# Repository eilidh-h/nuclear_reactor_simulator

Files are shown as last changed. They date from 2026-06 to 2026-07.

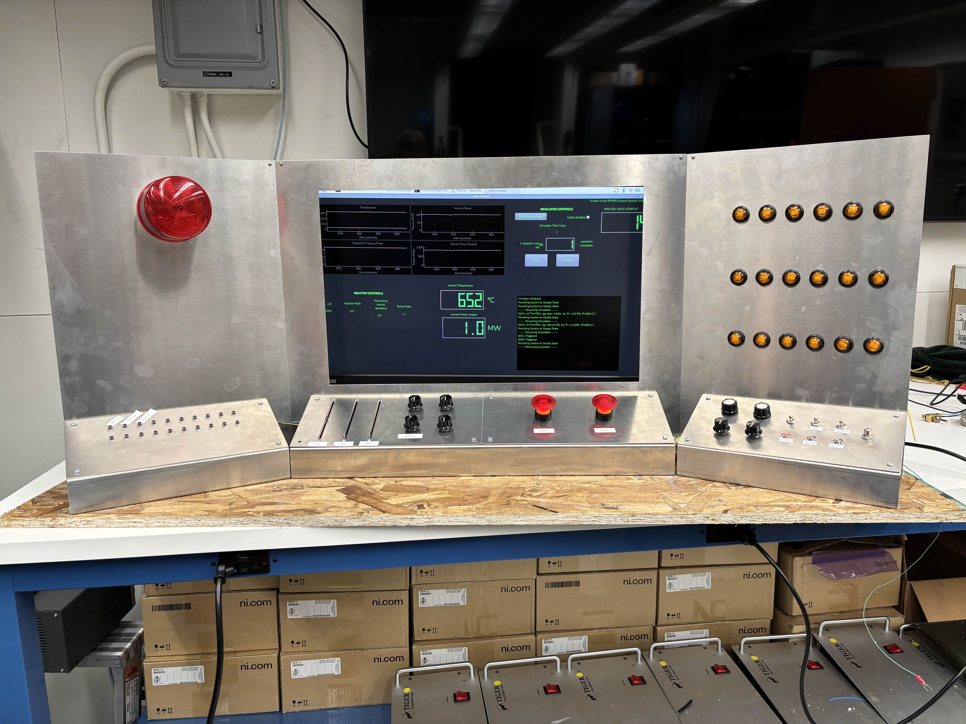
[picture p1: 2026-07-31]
Current Design Files/Case Files/Final Unit.jpg

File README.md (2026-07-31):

# CANDU Nuclear Reactor Simulator

# Project Overview
This project is a hardware-integrated CANDU reactor simulator built using Python, PyQt6, Raspberry Pi GPIO, ADC/DAC hardware, and a real-time reactor simulation backend. The system provides physical controls and indicators for interacting with a simulated reactor plant. This repository also houses a software only version of the simulation which can be run on any computer and does not require hardware inputs.

---

# Repository Structure

```text
main/
├── Current Design Files/        # Contains all hardware information
    ├── Datasheets/                  # Contains datasheets for parts used in the original design
    ├── Case Files/                  # Contains .SLDPRT drawings for the case and parts used
    ├── Circuitry Files/             # Contains modular circuit designs for each type of input
    ├── Fission Vision - Simulator Parts list.xlsx # Master list of all parts and costings
├── Hardware Version/            # Scripts for simulation with hardware
    ├── ADS1256.py                   # ADC driver
    ├── DAC8532.py                   # DAC driver
    ├── Hardware_Integrated_GUI.ui   # Qt Designer UI file
    ├── candu_realtime_sim.py        # Reactor simulation backend
    ├── main.py                      # hardware main script
    ├── pinouts.py                   # Raspberry Pi Pin out config
├── Software-Only Version/       # Scripts for simulation with software only
    ├── Software_Only_GUI.ui         # Qt Designer UI file
    ├── candu_realtime_sim.py        # Reactor simulation backend
    ├── main.py                      # software-only main script
└── README.md
```

---

# Hardware Requirements
The full parts list can be found in ```main/Current Design Files/Fission Vision - Simulator Parts List.xlsx ```

## Core Hardware

* Raspberry Pi 4 or 5
* MicroSD Card
* Power Supply
* Display/Monitor
* Keyboard/Mouse

## I/O Hardware

* ADS1256 ADC Module
* DAC8532 DAC Module
* Potentiometers / Rotary Knobs
* Toggle Switches
* Push Buttons
* LEDs / Indicator Lights
* Siren / Buzzer
* Wiring / Breadboard / PCB

---

# Software Requirements
## Operating System

* Raspberry Pi OS: Raspberry Pi OS (64-bit)

## Python Version

* Python 3.X Recommended

## Required Python Libraries

```bash
pip install pyqt6
pip install pyqtgraph
pip install numpy
pip install RPi.GPIO
pip install threading
```
---
# Software controls Overview

### `speed`
Sets the reactor simulation speed relative to real time.

- **Units:** Reactor seconds per wall-clock second
- **Example:**
  ```text
  speed = 60
  ```
  This means **1 real second = 1 reactor minute**.

---

### `goal`
Sets the operator's target power fraction.

This value is intended primarily for the simulator's game mode, where the operator attempts to match the requested power level.

---

### `lzc`
Sets the average Liquid Zone Controller (LZC) fill level.

- **Units:** Percent (%)
- **Neutral value:** `50%`
- **Behavior:**
  - Lower fill → Positive reactivity → Reactor power tends to increase.
  - Higher fill → Negative reactivity → Reactor power tends to decrease.

---

### `adj`
Sets the adjuster rod withdrawal fraction.

- **Range:** `0–1`
- **Behavior:**
  - Higher values correspond to greater adjuster rod withdrawal.
  - Increased withdrawal adds **positive reactivity**.

---

### `mca`
Sets the Mechanical Control Absorber (MCA) insertion fraction.

- **Range:** `0–1`
- **Behavior:**
  - Higher insertion results in **more negative reactivity**.

---

### `refuel`
Sets the continuous online refuelling command.

- **Range:** `0–2`
- Implemented as a continuous control rather than discrete fuelling events.
- Designed to map naturally to GUI sliders or analogue hardware controls.

---

### `safety`
Enables or disables the automatic reactor protection system.

When enabled, automatic **stepback** and **shutdown** logic will operate if required.

---

### `trip sds1`
Manually initiates a shutdown using **Shutdown System 1 (SDS1)**.

---

### `trip sds2`
Manually initiates a shutdown using **Shutdown System 2 (SDS2)**.

---

### `reset sds`
Clears the shutdown latches.

This command is only accepted when reactor power is **below 1% full power**.

---

### `reset steady`
Resets the simulator to the nominal startup state.

This performs a complete re initialization of the reactor state.

# Known simulation simplifications
* one delayed-neutron group instead of six
* lumped thermal states instead of detailed HTS / SG thermodynamics
* normalized poison states instead of full iodine/xenon number densities
* simplified shutdown logic compared with plant-grade 2-out-of-3 voting

---

# Future Improvements

Ideas for possible enhancements:
* Developing lesson materials for use with the simulator
* Creating interesting scenarios (power grid failure, start the reactor from cold, etc.)
* Adding an automatic mode like real CANDU reactors with a PID controller based on the steam pressure error
* Adding a graphic of a CANDU plant to the GUI to show how energy moves around the plant
* More robust simulation feedback and event logs
* Implementing a “power-matching” game mode
* Additional speed and performance testing and improvement
* Further refinements of the case to improve transport, packing, and ease of use

---

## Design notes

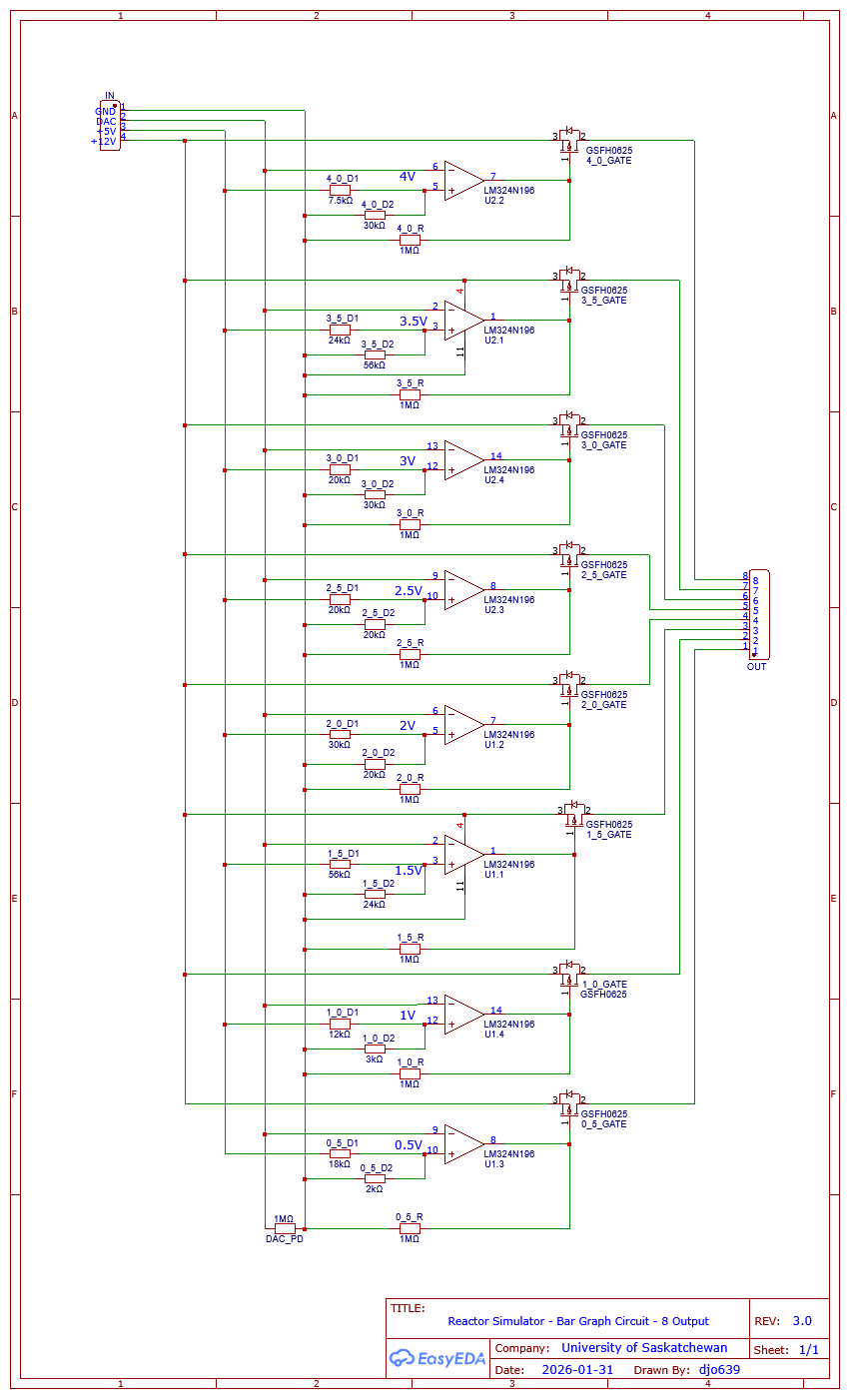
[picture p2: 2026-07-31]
Current Design Files/Circuitry Files/Schematics/Bar Graph - Schematic.png

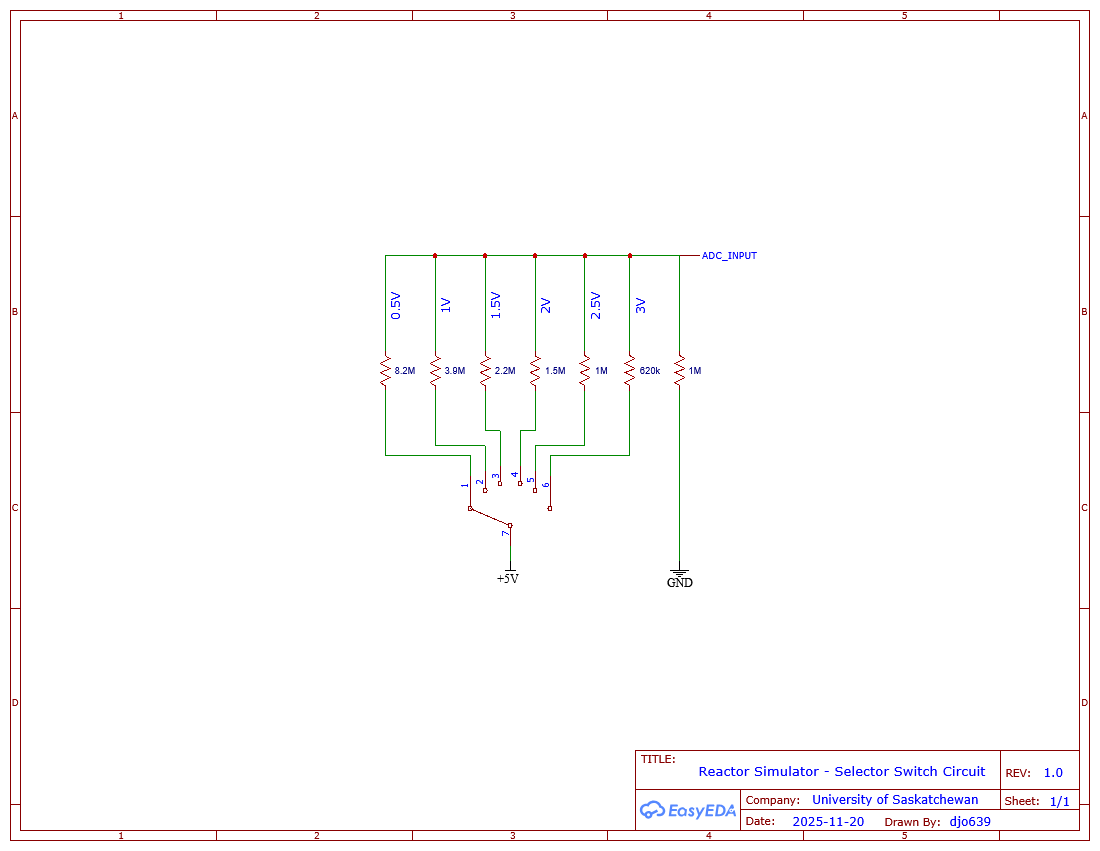
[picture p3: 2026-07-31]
Current Design Files/Circuitry Files/Schematics/Selector Swtich - Schematic.png

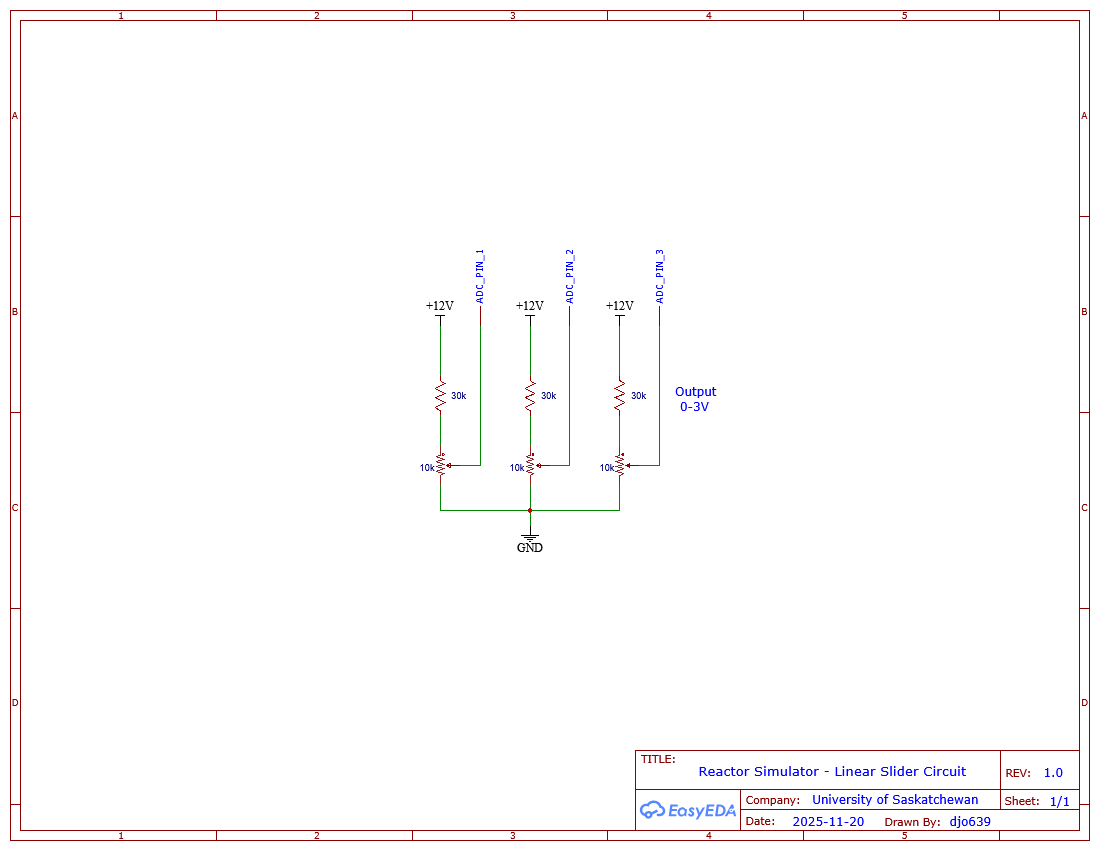
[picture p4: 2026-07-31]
Current Design Files/Circuitry Files/Schematics/3 Slider Circuit - Schematic.png

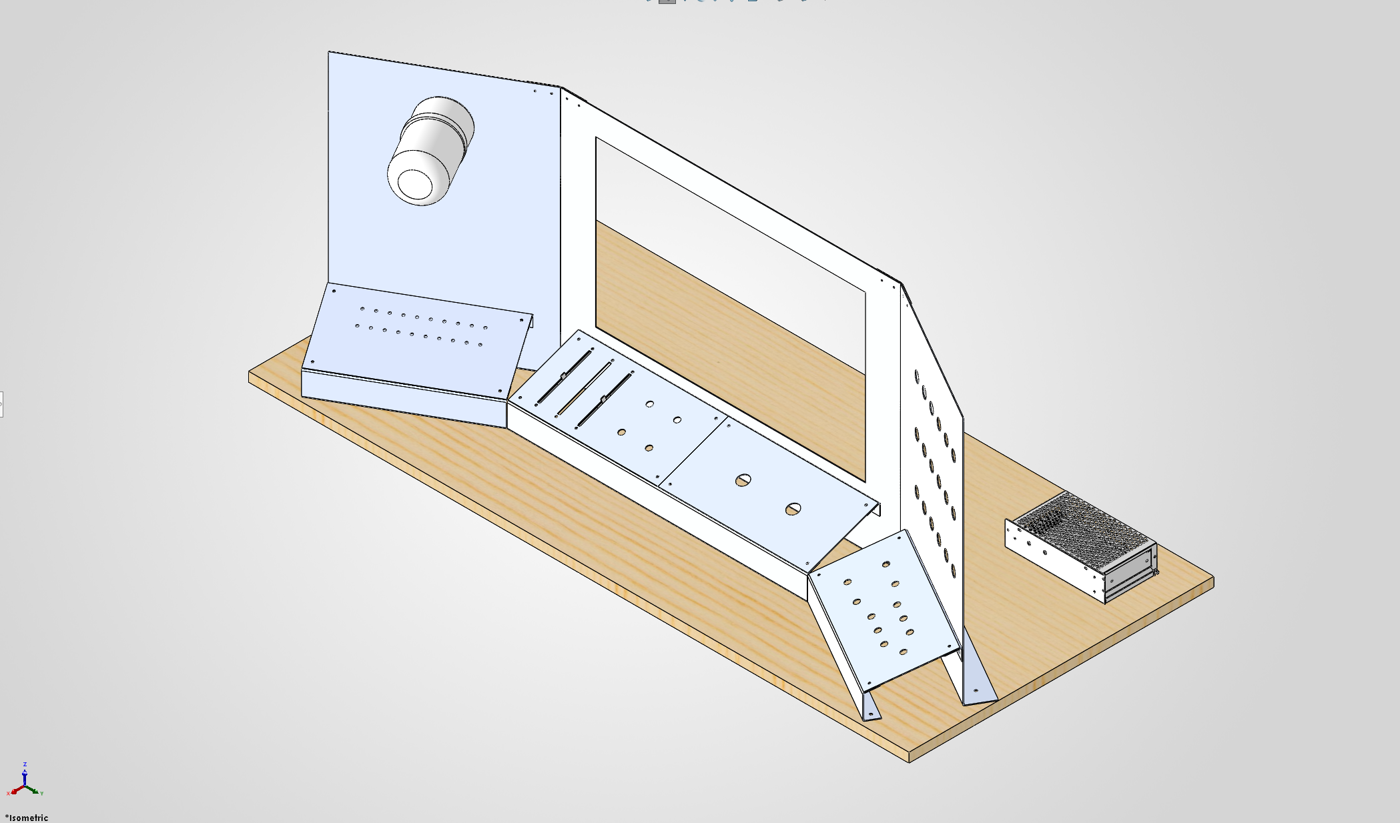
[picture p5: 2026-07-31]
Current Design Files/Case Files/Simulator Case - Solidworks Render.png

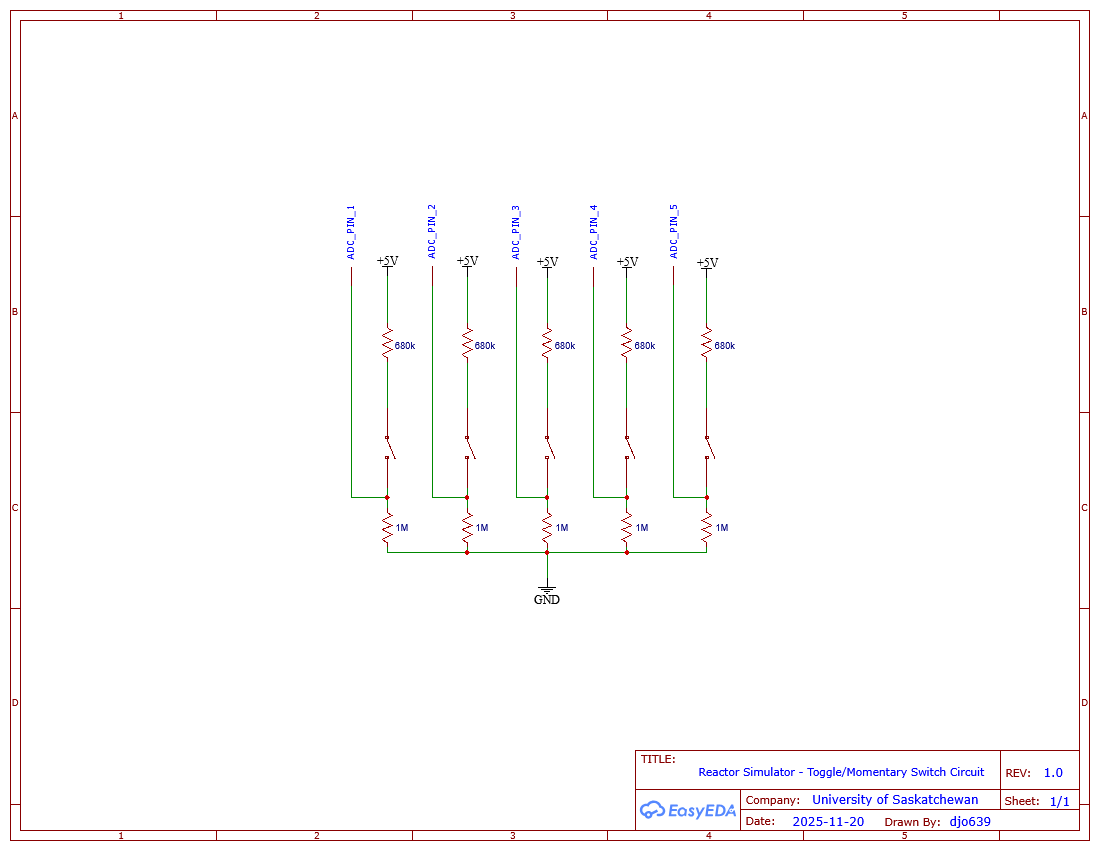
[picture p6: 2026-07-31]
Current Design Files/Circuitry Files/Schematics/Momentary_Toggle Switch - Schematic.png

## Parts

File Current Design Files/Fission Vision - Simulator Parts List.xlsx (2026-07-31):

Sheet: Complete Assembly List
COMPLETE ASSEMBLY LIST
*NOTE: Assembly details and component lists can be found within the sub-sheet of the same name. Costs are estimates only and do not include labor.
Type | Subtype | Component/Assembly | Name | Use | QTY | Approx Cost | Notes
Case | Back Panel | Assembly | Heat/Power/Pressure Panel | Vertical aluminum panel to support bar graph lights | 1 | $29.50
Case | Back Panel | Assembly | Monitor Panel | Vertical aluminum panel to support GUI monitor | 1 | $32.00
Case | Back Panel | Assembly | Siren Panel | Vertical aluminum panel to support meltdown siren | 1 | $41.00
Case | Control Panel | Assembly | Indicator | Aluminum panel to contain hazard/warning indicator lights | 1 | $41.00
Case | Control Panel | Assembly | Reactor Control | Aluminum panel to contain reactor controls for parameters such as Liquid Zone Control level, Adjuster Rods position, etc | 1 | $54.35
Case | Control Panel | Assembly | SCRAM | Alumimun panel to contain Reactor SCRAM controls | 1 | $35.05
Case | Control Panel | Assembly | Simulation Control | Aluminum panel to contain simulation controls for parameters such as pause, play, simulation speed, etc | 1 | $57.80
Case | Structure | Assembly | Simulator Base | Provides mounting points for simulator case, circuitry, and other components | 1 | $39.00 | 5/16" thickness minimum - other dimensions and hole pattern as per SolidWorks file
Case | Structure | Assembly | Mounting Hardware | Plates and components required to interconnect case panels | 1 | $48.70
Electrical | Circuit | Assembly | Bar Graph | Takes DAC output and converts to scaling bar graph lights | 2 | $40.60
Electrical | Circuit | Assembly | Pull Down | Pulls toggle/momentary/logic pins to 0V to prevent floating input errors | 1 | $11.25
Electrical | Circuit | Assembly | Selector Switch | Converts multi-output selector switch to single pin GPIO input | 1 | $11.10
Electrical | Circuit | Assembly | Siren Trigger | Allows Raspberry Pi to trigger 12V siren with low power 3.3V | 1 | $8.70
Electrical | Terminal | Component | Conn Barrier Strip | Local Voltage/Ground Mustering Point | 4 | $10.00 | 10 position - 0.374" - 1 for each third of the simulator triptych and 1 at rear for Pi and accessories
Electrical | Terminal | Component | D-SUB Connector (Female) | Provides quick connect/disconnect signal and power passthrough between Pi and controls | 1 | $2.50 | 50-Pin
Electrical | Terminal | Component | D-SUB Connector (Male) | Provides quick connect/disconnect signal and power passthrough between Pi and controls | 1 | $2.50 | 50-Pin
Electrical | Power | Component | Power Cable | Provides 120VAC wall power to power supply | 1 | $5.00 | 3-Pin 120VAC plug to bare wire or fork terminal - Connect directly to power supply or through rated toggle switch
Electrical | Power | Component | Power Supply | Powers all simulator functions except montior | 1 | $75.00 | 120VAC to Dual Output 5VDC/12VDC
Electrical | Power | Assembly | Wiring Harness | Connects all panels to central D-SUB Passthrough | 1 | $39.25
Electrical | Computation | Component | Raspberry Pi 5 | Hosts Simulation. Processes Analog IO | 1 | $250.00
Electrical | Raspberry Pi Module | Component | ADC/DAC | Allows Pi to Process Continuous IO | 1 | $60.00
Electrical | Raspberry Pi Module | Component | Micro HDMI to HDMI + Power | Allows Pi to accept standard HDMI interface. Enables Pi to run off 5V Power Supply | 1 | $20.00
Peripheral | GUI | Component | Monitor | Displays GUI | 1 | $150.00 | 27" minimum for proper fitment in panel cutout
Peripheral | GUI | Component | Monitor Arm | Holds monitor in place while still allowing for repositioning | 1 | $50.00
Peripheral | GUI | Component | Mouse | Initialize Reactor Simulator (Not required while simulation is running) | 1 | $10.00
Approximate Total Simulator Cost |  | $1124.30

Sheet: Indicator Control Panel
Indicator Control Panel - Part List
Name | Use | Voltage | QTY | Approx Per Unit Cost | Approx Cost | Notes
3mm Discrete LED Bulb | Simulator analog indication - warning lights | 3.3 | 20 | $0.50 | $10.00
3mm LED Panel Mount | Mount lights to control panel | - | 20 | $0.50 | $10.00
10-Pin Molex Connector (Male) | Quick Disconnect between panel and simulator | - | 4 | $1.25 | $5.00 | 2 for signal, 2 for ground
16ga Aluminum Sheet | Control Mounting | - | 1 | $10.00 | $10.00 | Dimensioned as per Solidworks file. Assumes Aluminum price of $5 per square foot
Heat Shrink 1/8" | Isolation | - | 1 | $1.00 | $1.00 | 1-2ft, 2:1 shrink ratio sufficient
Heat Shrink 1/4" | Isolation | - | 1 | $1.00 | $1.00 | 1-2ft, 2:1 shrink ratio sufficient
Wire | 20-22AWG | - | 10 | $0.30 | $3.00 | 10ft - Four separate colors prefered (12V, 5V, Signal, Ground)
820 kΩ Resistor | LED Resistance | 3.3 | 20 | $0.05 | $1.00 | Assumes Red LED: Forward Voltage 1.75V and Current 2mA
 |  |  |  | Approximate Total Cost | $41.00

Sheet: Reactor Control Panel
Reactor Control Panel - Part List
Name | Use | Voltage | QTY | Approx Per Unit Cost | Approx Cost | Notes
Rotatry Potentiometer | Analog Simulator Inputs | 12 | 4 | $2.50 | $10.00
Rotatry Potentiometer Cap | Simulator Control Surface | - | 4 | $0.75 | $3.00
Slider Potentiometer | Analog Simulator Inputs | 12 | 3 | $6.00 | $18.00
Slider Potentiometer Cap | Simulator Control Surface | - | 3 | $1.00 | $3.00
3-Pin Molex Connector (Male) | Quick Disconnect between panel and simulator | - | 1 | $1.25 | $1.25 | Slider pots signal out
4-Pin Molex Connector (Male) | Quick Disconnect between panel and simulator | - | 1 | $1.25 | $1.25 | Rotary pots signal out
8-Pin Molex Connector (Male) | Quick Disconnect between panel and simulator | - | 2 | $1.25 | $2.50 | 1 for common 12V supply, 1 for common ground
16ga Aluminum Sheet | Control Mounting | - | 1 | $10.00 | $10.00 | Dimensioned as per Solidworks file. Assumes Aluminum price of $5 per square foot
Heat Shrink 1/8" | Isolation | - | 1 | $1.00 | $1.00 | 1-2ft, 2:1 shrink ratio sufficient
Heat Shrink 1/4" | Isolation | - | 1 | $1.00 | $1.00 | 1-2ft, 2:1 shrink ratio sufficient
Wire | 20-22AWG | - | 10 | $0.30 | $3.00 | 10ft - Four separate colors prefered (12V, 5V, Signal, Ground)
30 kΩ Resistance | Convert 12V Slider Input to output 0-3V | 12 | 3 | $0.05 | $0.15
750 kΩ Resistance | Convert 12V Potentiometer Input to output 0-3V | 12 | 4 | $0.05 | $0.20
 |  |  |  | Approximate Total Cost | $54.35
 |  |  |  |  |  |  | 0.75

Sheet: SCRAM Control Panel
SCRAM Control Panel - Part List
Name | Use | Voltage | QTY | Approx Per Unit Cost | Approx Cost | Notes
Lit Emergency Stop Slap Switch | Simulator analog control | 5 | 2 | $10.00 | $20.00 | Wire so that switch light in series with switch contact
2-Pin Molex Connector (Male) | Quick Disconnect between panel and simulator | - | 3 | $1.25 | $3.75 | 1 for both switch outputs, 1 for common 5V supply, 1 for common ground
16ga Aluminum Sheet | Control Mounting | - | 1 | $10.00 | $10.00 | Dimensioned as per Solidworks file. Assumes Aluminum price of $5 per square foot
Wire | 20-22AWG | - | 4 | $0.30 | $1.20 | 4ft - Four separate colors prefered (12V, 5V, Signal, Ground)
680 kΩ Resistance | Convert 5V switch output 3V | 5 | 2 | $0.05 | $0.10 | Attach resistor to power supply lead of switch - signal lead must be connected to Pi through Pulldown circuit.
 |  |  |  | Approx Total Cost | $35.05

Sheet: Simulation Control Panel
Simulator Control Panel - Part List
Name | Use | Voltage | QTY | Approx Per Unit Cost | Approx Cost | Notes
Rotatry Potentiometer | Analog Simulator Inputs | 12 | 2 | $2.50 | $5.00
Rotatry Potentiometer Cap | Simulator Control Surface | - | 2 | $0.75 | $1.50
Selector Switch | Analog Simulator Inputs | 5 | 2 | $10.00 | $20.00
Selector Switch Cap | Simulator Control Surface | - | 2 | $1.00 | $2.00
Toggle Switch | Analog Simulator Inputs | 5 | 7 | $2.00 | $14.00
10-Pin Molex Connector (Male) | Quick Disconnect between panel and simulator | - | 2 | $1.25 | $2.50
16ga Aluminum Sheet | Control Mounting | - | 1 | $10.00 | $10.00 | Dimensioned as per Solidworks file. Assumes Aluminum price of $5 per square foot
Heat Shrink 1/8" | Isolation | - | 1 | $1.00 | $1.00 | 1-2ft, 2:1 shrink ratio sufficient
Heat Shrink 1/4" | Isolation | - | 1 | $1.00 | $1.00 | 1-2ft, 2:1 shrink ratio sufficient
680 kΩ Resistance | Convert 5V switch output 3V | 5 | 6 | $0.05 | $0.30 | Attach resistor to power supply lead of switch - signal lead must be connected to Pi through Pulldown circuit.
750 kΩ Resistance | Convert 12V Potentiometer Input to output 0-3V | 12 | 4 | $0.05 | $0.20
Wire | 20-22AWG | - | 1 | $0.30 | $0.30 | 20ft - Four separate colors prefered (12V, 5V, Signal, Ground)
 |  |  |  | Approx Total Cost | $57.80

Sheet: Simulator Base
Simulator Base - Part List
Name | Use | QTY | Approx Per Unit Cost | Approx Cost | Notes
Hanger Bolts | Case Mounting Point | 20 | $0.15 | $3.00 | M4 x 25mm
Washer | Mounting Hardware | 20 | $0.05 | $1.00 | M4
Wing Nut | Mounting Hardware | 20 | $0.25 | $5.00 | M4
Plywood | Simulator Base | 1 | $30.00 | $30.00 | 5/16" minimum - complete dimensions and hole pattern available in SolidWorks file
 |  |  | Approx Total Cost | $39.00

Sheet: Monitor Panel
Monitor Panel - Part List
Name | Use | QTY | Approx Per Unit Cost | Approx Cost | Notes
14ga Aluminum Sheet |  | 4 | $8.00 | $32.00 | Dimensioned as per Solidworks file. Assumes Aluminum price of $8 per square foot
 |  |  | Approx Total Cost | $32.00

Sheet: Siren Panel
Siren Panel - Part List
Name | Use | QTY | Approx Per Unit Cost | Approx Cost | Notes
Beacon w/ Siren | Alarm | 1 | $25.00 | $25.00 | Beacon Preferred. Avoid strobe.
14ga Aluminum Sheet | Simulator Base | 2 | $8.00 | $16.00 | Dimensioned as per Solidworks file. Assumes Aluminum price of $8 per square foot
 |  |  | Approx Total Cost | $41.00

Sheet: HPP Panel
Heat/Power/Pressure Panel - Part List
Name | Use | QTY | Approx Per Unit Cost | Approx Cost | Notes
Trailer Side Clearance/Marker LEDs - Amber | Bar Graph Indication | 18 | $0.75 | $13.50 | 3/4" dia - 12VDC
14ga Aluminum Sheet |  | 2 | $8.00 | $16.00 | Dimensioned as per Solidworks file. Assumes Aluminum price of $5 per square foot
 |  |  | Approx Total Cost | $29.50

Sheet: Mounting Hardware
Mounting Hardware - Part List
Name | Use | QTY | Approx Cost Per Unit | Approx Cost | Notes
Angle Bracket | Ties vertical panels together | 2 | $0.10 | $0.20 | 150° bend - 16ga aluminum preferred
Bottom Panel Mount - Center | Mounting Plate | 1 | $5.00 | $5.00 | Dimensions, bend angle, and hole pattern as per Solidworks file
Bottom Panel Mount - Wing | Mounting Plate | 2 | $5.00 | $10.00 | Dimensions, bend angle, and hole pattern as per Solidworks file
Machine Screw - Cheesehead - M3 | Bracket Mounting | 4 | $0.10 | $0.40 | Slotted - 0.25" Long - Cheesehead for aesthetics only. Substitute with whatever you like
Machine Screw - Cheesehead - M4 | Panel Mounting | 16 | $0.10 | $1.60 | Slotted - 0.5" Long - Cheesehead for aesthetics only. Substitute with whatever you like
Machine Screw - Panhead - M5 | Panel Mounting | 10 | $0.10 | $1.00 | Robertson - 0.5" Long
Rivnut | Panel Mounting | 16 | $0.10 | $1.60 | M4 - Steel or Aluminum
Upper Panel Mount - Center | Mounting Plate | 1 | $5.00 | $5.00 | Dimensions, bend angle, and hole pattern as per Solidworks file
Upper Panel Mount - Wing | Mounting Plate | 2 | $5.00 | $10.00 | Dimensions, bend angle, and hole pattern as per Solidworks file
Washer - M3 | Bracket Mounting | 8 | $0.05 | $0.40 | -
Washer - M5 | Panel Mounting | 20 | $0.05 | $1.00 | -
Wingnut - M5 | Panel Mounting | 10 | $0.25 | $2.50 | -
Nylon Stand-Off | Circuit Mounting | 20 | $0.50 | $10.00 | #6UNC - 0.5" Long
 |  |  | Approximate Total Cost | $48.70

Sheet: Bar Graph Circuit
Bar Graph Circuit - Part List
Name | Use | QTY | Approx Price Per Unit | Approx Cost | Notes
1 MΩ Resistance | Pulldown Resistor | 7 | $0.05 | $0.35 | 0.25 W - Axial Through Hole
12 kΩ Resistance | Comparator Reference Divider | 1 | $0.05 | $0.05 | 0.25 W - Axial Through Hole
18 kΩ Resistance | Comparator Reference Divider | 1 | $0.05 | $0.05 | 0.25 W - Axial Through Hole
2 kΩ Resistance | Comparator Reference Divider | 1 | $0.05 | $0.05 | 0.25 W - Axial Through Hole
2 Position Screw Terminal | Wire-to-board connection | 2 | $0.65 | $1.30 | 0.1" pitch - 16-30AWG
20 kΩ Resistance | Comparator Reference Divider | 4 | $0.05 | $0.20 | 0.25 W - Axial Through Hole
24 kΩ Resistance | Comparator Reference Divider | 1 | $0.05 | $0.05 | 0.25 W - Axial Through Hole
3 kΩ Resistance | Comparator Reference Divider | 1 | $0.05 | $0.05 | 0.25 W - Axial Through Hole
30 kΩ Resistance | Comparator Reference Divider | 2 | $0.05 | $0.10 | 0.25 W - Axial Through Hole
56 kΩ Resistance | Comparator Reference Divider | 1 | $0.05 | $0.05 | 0.25 W - Axial Through Hole
6 Position Screw Terminal | Wire-to-board connection | 1 | $2.35 | $2.35 | 0.1" pitch - 16-30AWG
Hook-up Wire | - | 3 | $0.30 | $0.90 | Assuming 3ft of 22AWG solid core - various colors preferred
IC Socket | IC-to-board connection | 2 | $0.20 | $0.40 | DIP-14
LM324 Op-Amp | Comparator Trigger | 2 | $0.35 | $0.70 | Part Number: LM324N (Texas Instruments)
Protoboard | Circuit PCB | 1 | $8.00 | $8.00 | 100mm x 80mm - 0.1" Pitch - Strip type board preferred
P-Type Mosfet | Isolation/Amplification | 6 | $0.95 | $5.70 | Part Number: GSFH0625 (Good-Ark Semiconductor)
 |  |  | Approx Total Cost | $20.30

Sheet: Siren Trigger Circuit
Siren Trigger Circuit - Part List
Name | Use | QTY | Approx Price Per Unit | Approx Cost | Notes
1 MΩ Resistance | Pulldown Resistor | 3 | $0.05 | $0.15 | 0.25 W - Axial Through Hole
2 Position Screw Terminal | Wire-to-board connection | 3 | $0.65 | $1.95 | 0.1" pitch
200 kΩ Resistance | Comparator Reference Divider | 1 | $0.05 | $0.05 | 0.25 W - Axial Through Hole
470 kΩ Resistance | Comparator Reference Divider | 1 | $0.05 | $0.05 | 0.25 W - Axial Through Hole
IC Socket | IC-to-board connection | 1 | $0.20 | $0.20 | DIP-14
LM324 Op-Amp | Comparator Trigger | 1 | $0.35 | $0.35 | Part Number: LM324N (Texas Instruments)
Protoboard | Circuit PCB | 1 | $5.00 | $5.00 | 31mm x 76mm - 0.1" Pitch - Bus type board preferred
P-Type Mosfet | Isolation/Amplification | 1 | $0.95 | $0.95 | Part Number: GSFH0625 (Good-Ark Semiconductor)
 |  |  | Approx Total Cost | $8.70

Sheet: Selector Switch Circuit
Selector Switch Circuit - Part List
*NOTE: Assumes 2 switch circuit with 6 positions each
Name | Use | QTY | Approx Cost Per Unit | Approx Cost | Notes
1 MΩ Resistance | Pulldown Resistor | 2 | $0.05 | $0.10 | 0.25 W - Axial Through Hole
2 Position Screw Terminal | Wire-to-board connection | 2 | $0.65 | $1.30 | 0.1" pitch
6 Position Screw Terminal | Wire-to-board connection | 2 | $2.35 | $4.70 | 0.1" pitch
Protoboard | Circuit PCB | 1 | $5.00 | $5.00 | 31mm x 76mm - 0.1" Pitch - Bus type board preferred
 |  |  | Approx Total Cost | $11.10

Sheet: Pull Down Circuit
Pull Down Circuit - Part List
*NOTE: Assumes 8 position circuit
Name | Use | QTY | Approx Cost per Unit | Approx Cost | Notes
1 MΩ Resistance | Pulldown Resistor | 8 | $0.05 | $0.40 | 0.25 W - Axial Through Hole
2 Position Screw Terminal | Wire-to-board connection | 9 | $0.65 | $5.85 | 0.1" pitch
Protoboard | Circuit PCB | 1 | $5.00 | $5.00 | 31mm x 76mm - 0.1" Pitch - Bus type board preferred
 |  |  | Approximate Total Cost | $11.25

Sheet: Wiring Harness
Wiring Harness - Part List
Name | Use | QTY | Approx Price per Unit | Approx Cost | Notes
Wire | - | 50 | $0.30 | $15.00 | 20-22AWG - 50ft - Four separate colors prefered (12V, 5V, Signal, Ground) - Can substitute for multiconductor cable were appropriate.
Fork Terminal (Red) | Electrical Connections | 25 | $0.10 | $2.50
Butt Splice Connector (Red) | Electrical Connections | 25 | $0.10 | $2.50
Fork Terminal (Blue) | Electrical Connections | 10 | $0.10 | $1.00
Butt Splice Connector (Blue) | Electrical Connections | 20 | $0.10 | $2.00
10-Pin Molex Connector (Female) | Quick Disconnect between panel and simulator | 6 | $1.25 | $7.50
8-Pin Molex Connector (Female) | Quick Disconnect between panel and simulator | 2 | $1.25 | $2.50
4-Pin Molex Connector (Female) | Quick Disconnect between panel and simulator | 1 | $1.25 | $1.25
3-Pin Molex Connector (Female) | Quick Disconnect between panel and simulator | 1 | $1.25 | $1.25
2-Pin Molex Connector (Female) | Quick Disconnect between panel and simulator | 3 | $1.25 | $3.75
40-pin GPIO connector ribbon cable | Quick Disconnect between controls and Raspberry Pi | 1 | $5.00 | $5.00
 |  |  | Approx Total Cost | $39.25

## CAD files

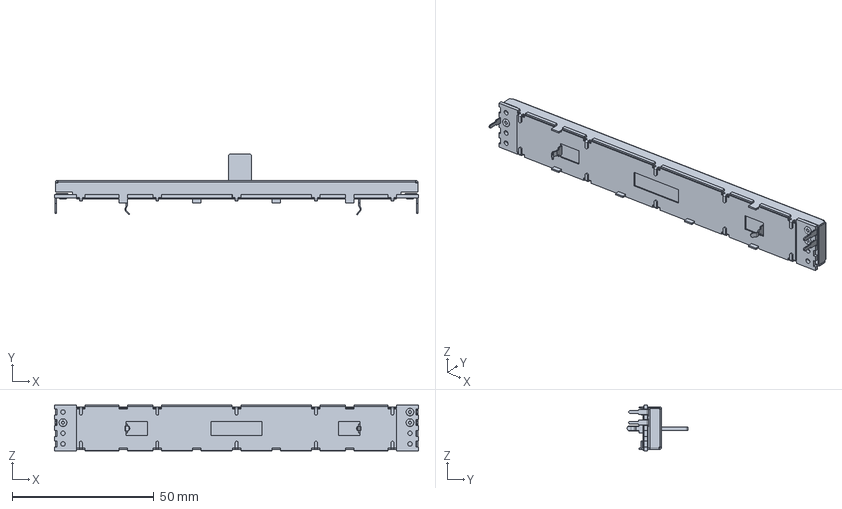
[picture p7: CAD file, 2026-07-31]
Current Design Files/Case Files/Part & Assembly Files/Slider - ptb0143-2010bp.stp
128.5 x 21.4 x 16.2 mm

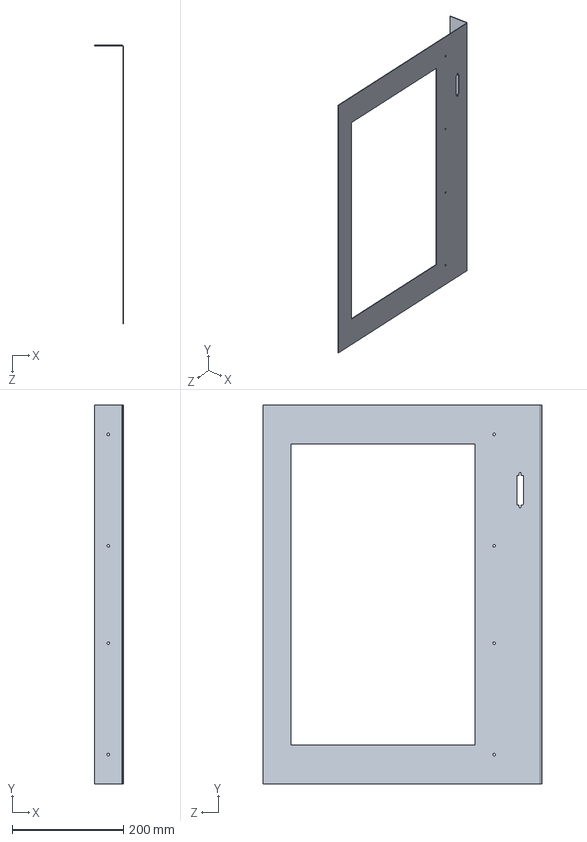
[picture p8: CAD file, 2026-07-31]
Current Design Files/Case Files/Part & Assembly Files/SIM_CNTR_001.SLDPRT
52.5 x 680.0 x 500.0 mm

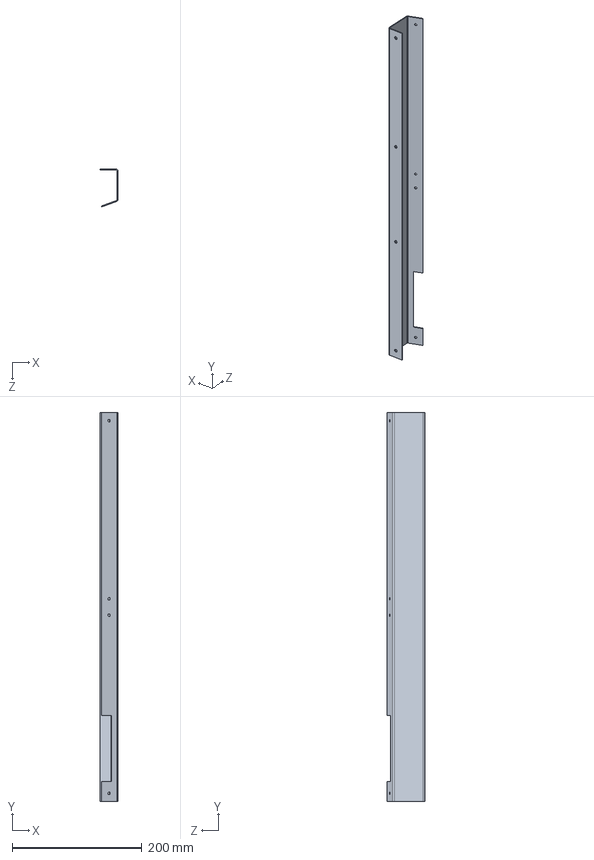
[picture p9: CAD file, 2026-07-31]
Current Design Files/Case Files/Part & Assembly Files/SIM_PMNT_CTR_BTM_001.SLDPRT
27.9 x 600.0 x 58.4 mm

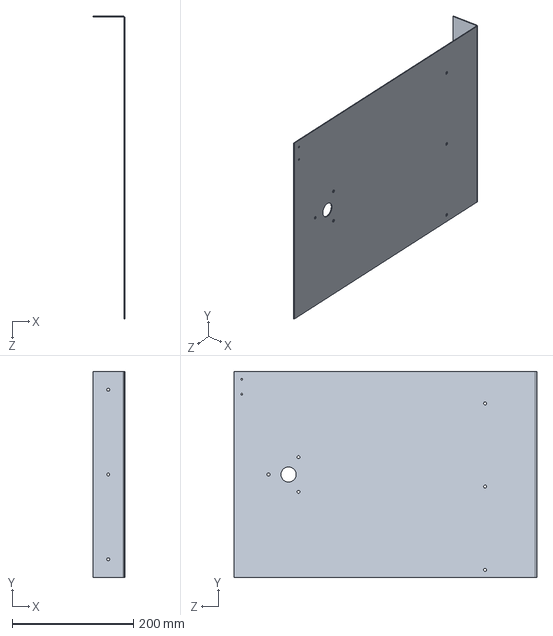
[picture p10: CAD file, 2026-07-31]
Current Design Files/Case Files/Part & Assembly Files/SIM_WING_LEFT_001.SLDPRT
52.5 x 340.0 x 500.0 mm

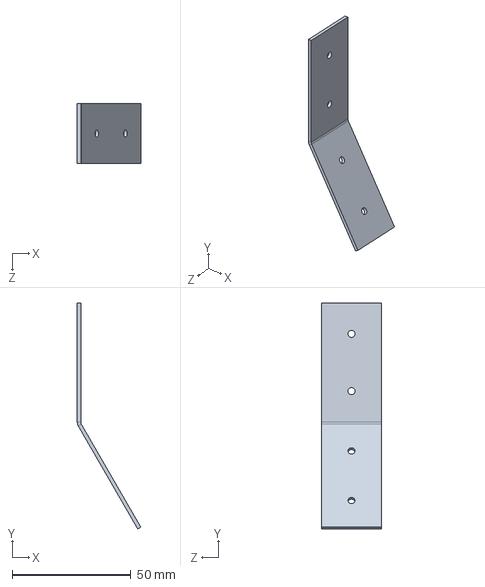
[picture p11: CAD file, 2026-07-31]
Current Design Files/Case Files/Part & Assembly Files/SIM_BRACKET_001.SLDPRT
26.8 x 95.2 x 25.4 mm

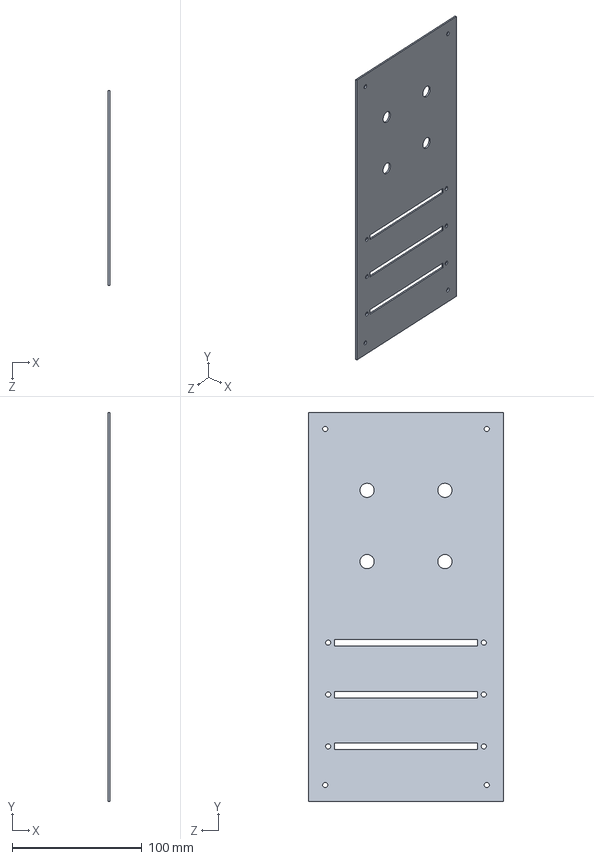
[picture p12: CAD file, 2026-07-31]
Current Design Files/Case Files/Part & Assembly Files/SIM_REACTOR_PNL_001.SLDPRT
1.52 x 300.0 x 150.0 mm

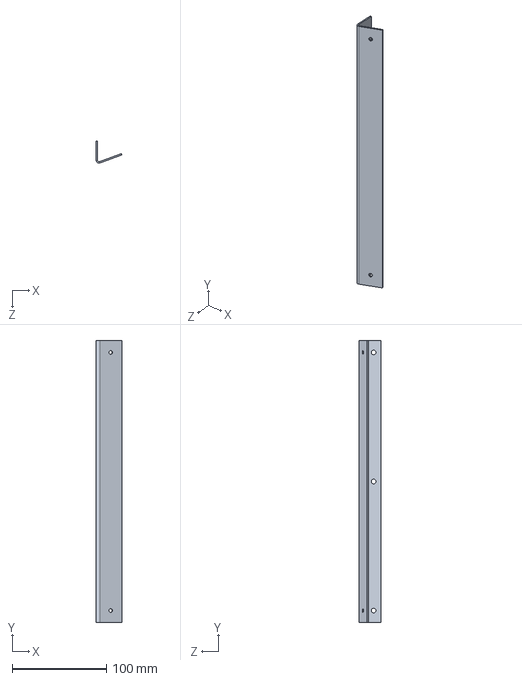
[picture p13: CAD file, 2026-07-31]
Current Design Files/Case Files/Part & Assembly Files/SIM_PMNT_W_TOP_001.SLDPRT
27.5 x 300.0 x 23.7 mm

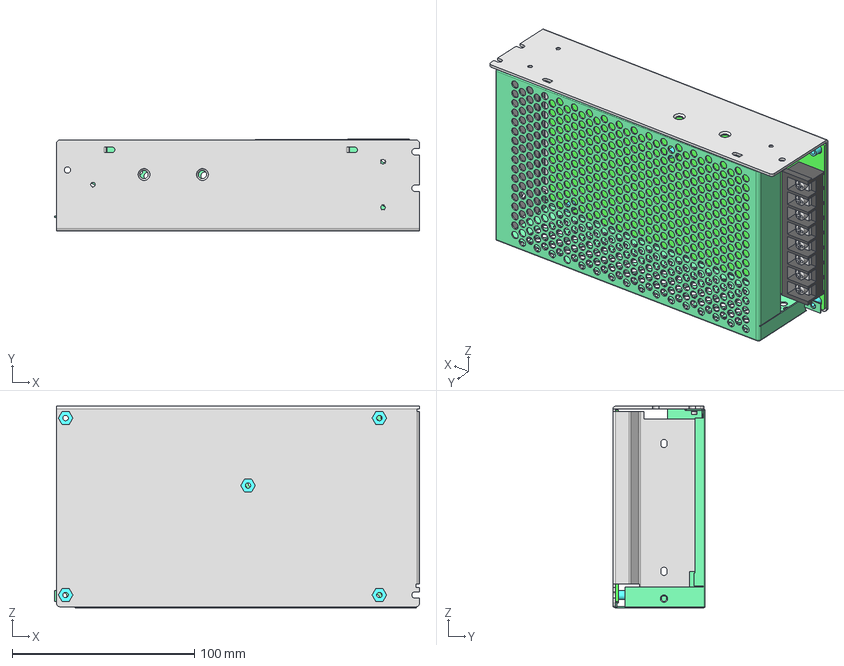
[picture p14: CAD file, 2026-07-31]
Current Design Files/Case Files/Part & Assembly Files/Power Supply - ADS-155.stp
200.1 x 50.5 x 110.5 mm
906-D
NUT
NUT_CPY
NUT_CPY1
NUT_CPY2
NUT_CPY3
NU
NU_CPY
NU_CPY1
ADD-155-pcb
ADD-155-T
TB

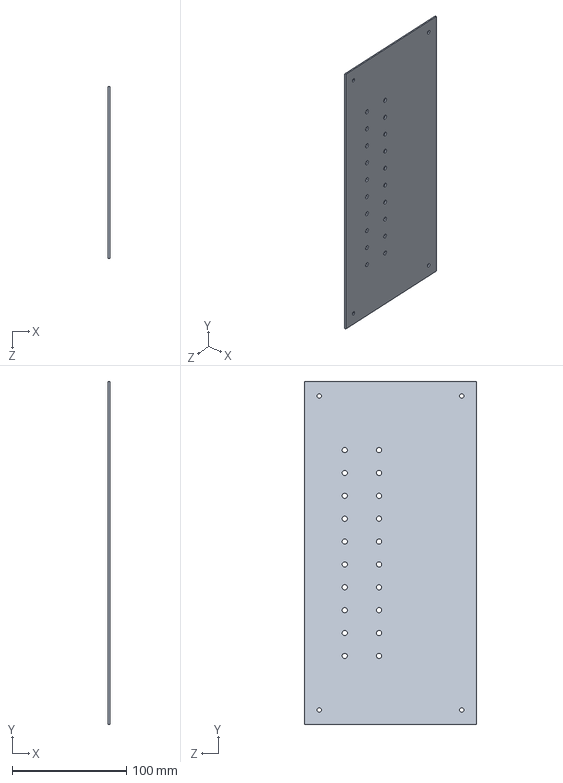
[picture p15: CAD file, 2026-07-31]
Current Design Files/Case Files/Part & Assembly Files/SIM_ALARM_PNL_001.SLDPRT
1.52 x 300.0 x 150.0 mm

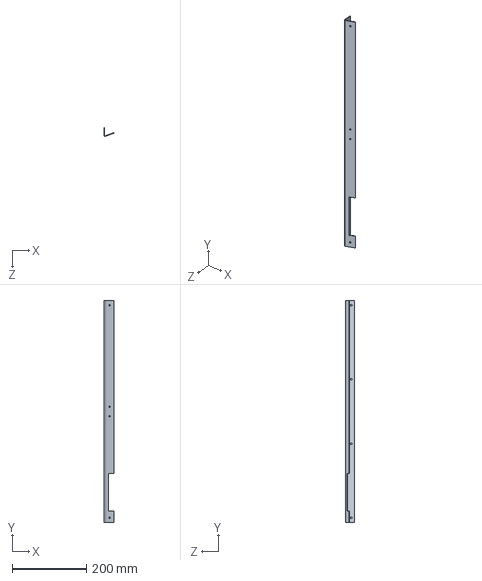
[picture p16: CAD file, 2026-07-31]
Current Design Files/Case Files/Part & Assembly Files/SIM_PMNT_CTR_TOP_001.SLDPRT
27.5 x 600.0 x 23.7 mm

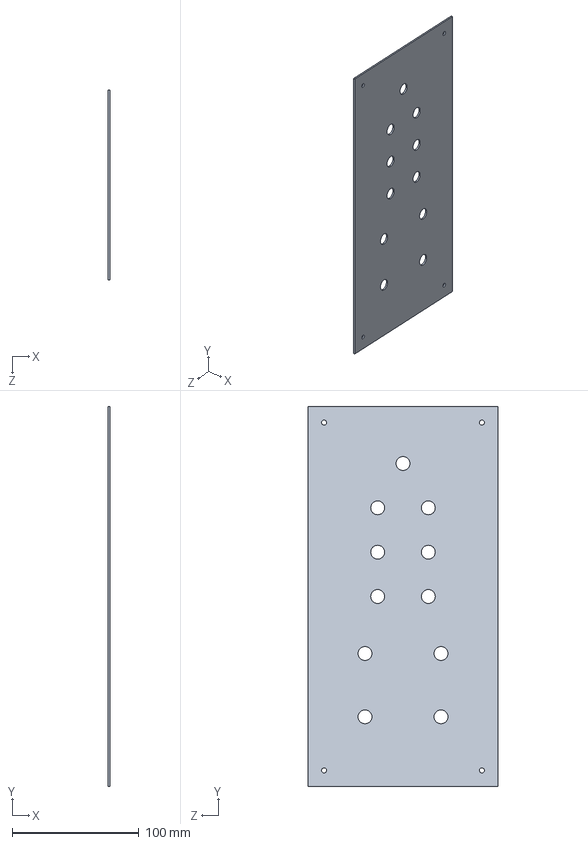
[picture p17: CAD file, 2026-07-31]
Current Design Files/Case Files/Part & Assembly Files/SIM_SIMCTRL_PNL_001.SLDPRT
1.52 x 300.0 x 150.0 mm

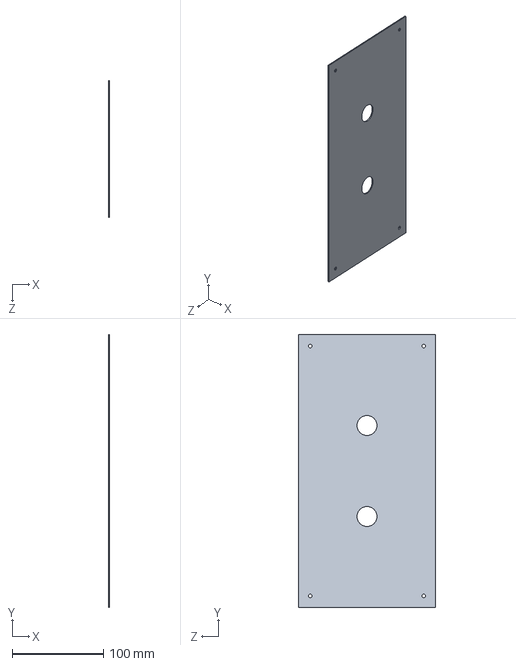
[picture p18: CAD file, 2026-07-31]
Current Design Files/Case Files/Part & Assembly Files/SIM_SCRAM_PNL_001.SLDPRT
1.30 x 300.0 x 150.0 mm

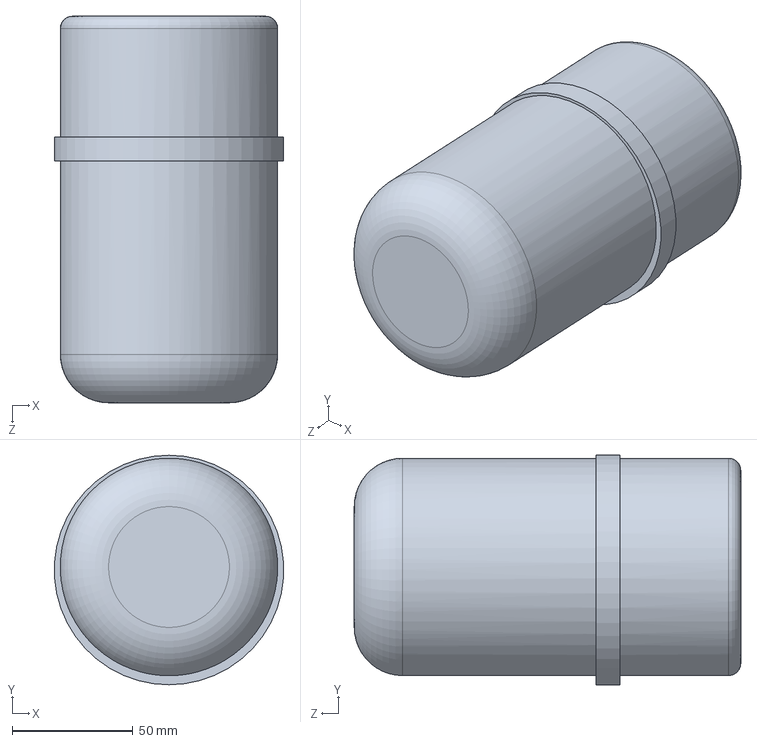
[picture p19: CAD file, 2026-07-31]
Current Design Files/Case Files/Part & Assembly Files/Alarm Beacon.SLDPRT
94.8 x 95.0 x 160.0 mm

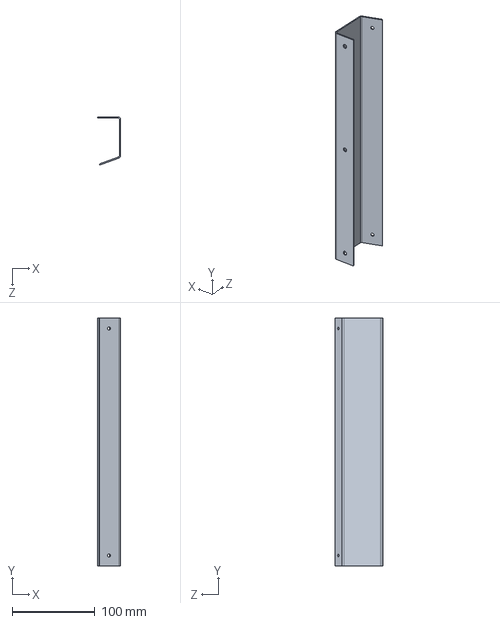
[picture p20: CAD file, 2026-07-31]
Current Design Files/Case Files/Part & Assembly Files/SIM_PMNT_W_BTM_001.SLDPRT
27.9 x 300.0 x 58.4 mm

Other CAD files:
Current Design Files/Case Files/Part & Assembly Files/SIM_OVERVIEW_001_002.SLDASM
Current Design Files/Case Files/Part & Assembly Files/SIM_WING_RIGHT_001.SLDPRT
Current Design Files/Case Files/Part & Assembly Files/SIM_BASE_001.SLDPRT
Current Design Files/Case Files/Drawing Files/SLDDRW Files/SIM_ALARM_PNL_001.SLDDRW
Current Design Files/Case Files/Drawing Files/SLDDRW Files/SIM_BASE_001.SLDDRW
Current Design Files/Case Files/Drawing Files/SLDDRW Files/SIM_BRACKET_001.SLDDRW
Current Design Files/Case Files/Drawing Files/SLDDRW Files/SIM_CNTR_001.SLDDRW
Current Design Files/Case Files/Drawing Files/SLDDRW Files/SIM_OVERVIEW_001_002.SLDDRW
Current Design Files/Case Files/Drawing Files/SLDDRW Files/SIM_PMNT_CTR_BTM_001.SLDDRW
Current Design Files/Case Files/Drawing Files/SLDDRW Files/SIM_PMNT_CTR_TOP_001.SLDDRW
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

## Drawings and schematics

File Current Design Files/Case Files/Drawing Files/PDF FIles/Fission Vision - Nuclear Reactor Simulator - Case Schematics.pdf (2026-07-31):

D | D

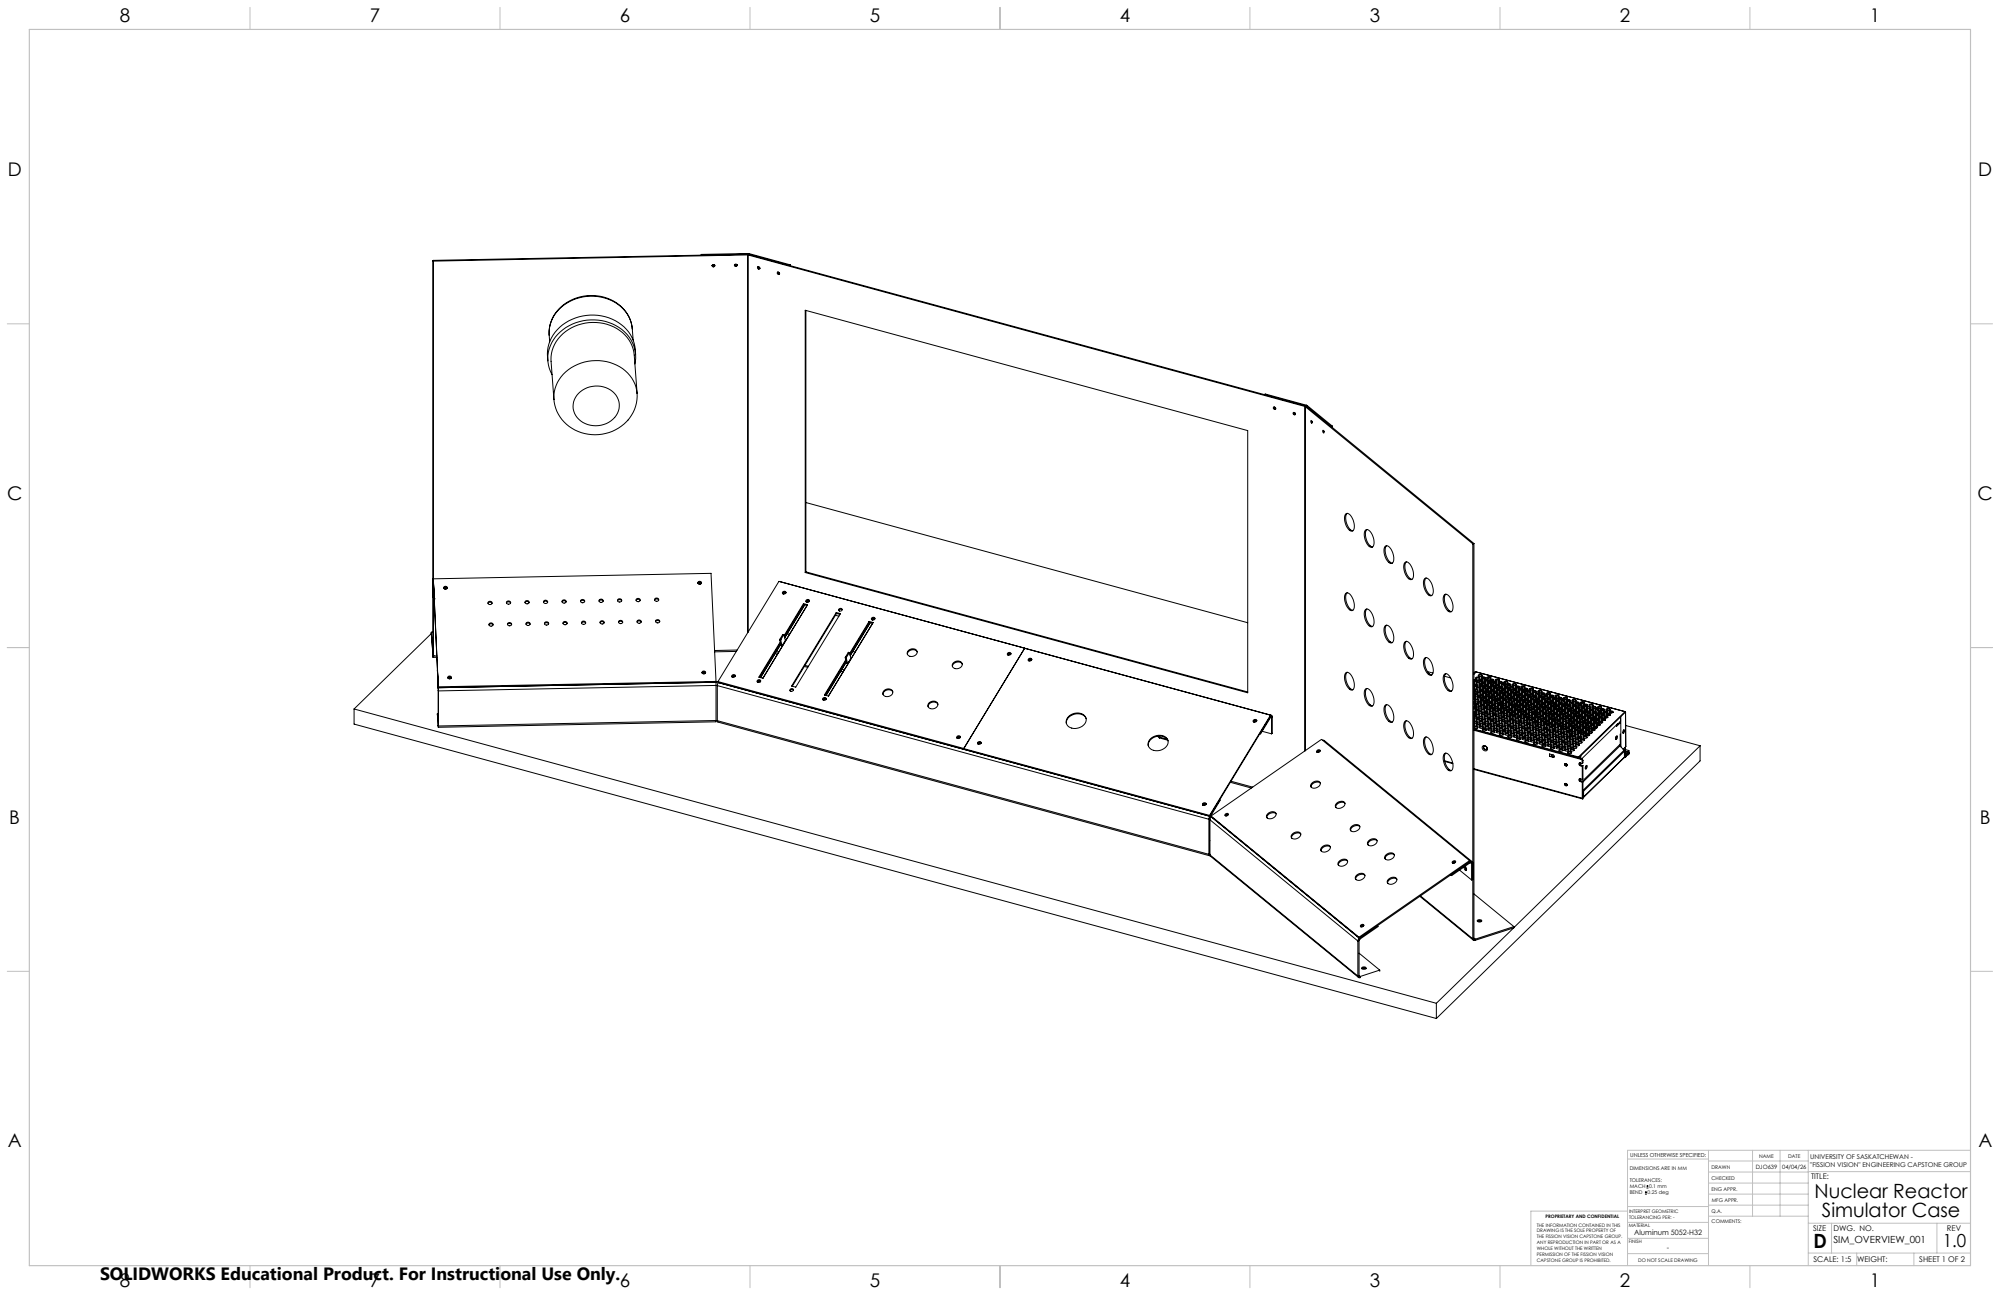
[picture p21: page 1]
Aluminum 5052-H32; DO NOT SCALE DRAWING; SHEET 1 OF 2; SCALE: 1:5; WEIGHT:; DWG. NO.; REV; SIZE; COMMENTS:; - FINISH; MATERIAL; SIM_OVERVIEW_001

UNLESS OTHERWISE SPECIFIED: | | NAME | DATE | UNIVERSITY OF SASKATCHEWAN -"FISSION VISION" ENGINEERING CAPSTONE GROUP
DIMENSIONS ARE IN MM TOLERANCES: MACH 0.1 mm BEND 0.25 deg | DRAWN | DJO639 | 04/04/26

CHECKED | | | TITLE: Nuclear Reactor Simulator Case

ENG APPR.
MFG APPR.

PROPRIETARY AND CONFIDENTIAL
THE INFORMATION CONTAINED IN THIS
DRAWING IS THE SOLE PROPERTY OF
THE FISSION VISION CAPSTONE GROUP.
ANY REPRODUCTION IN PART OR AS A
WHOLE WITHOUT THE WRITTEN
PERMISSION OF THE FISSION VISION
CAPSTONE GROUP IS PROHIBITED.

INTERPRET GEOMETRIC TOLERANCING PER: - | Q.A.

SOLIDWORKS Educational Product. For Instructional Use Only.

D | D

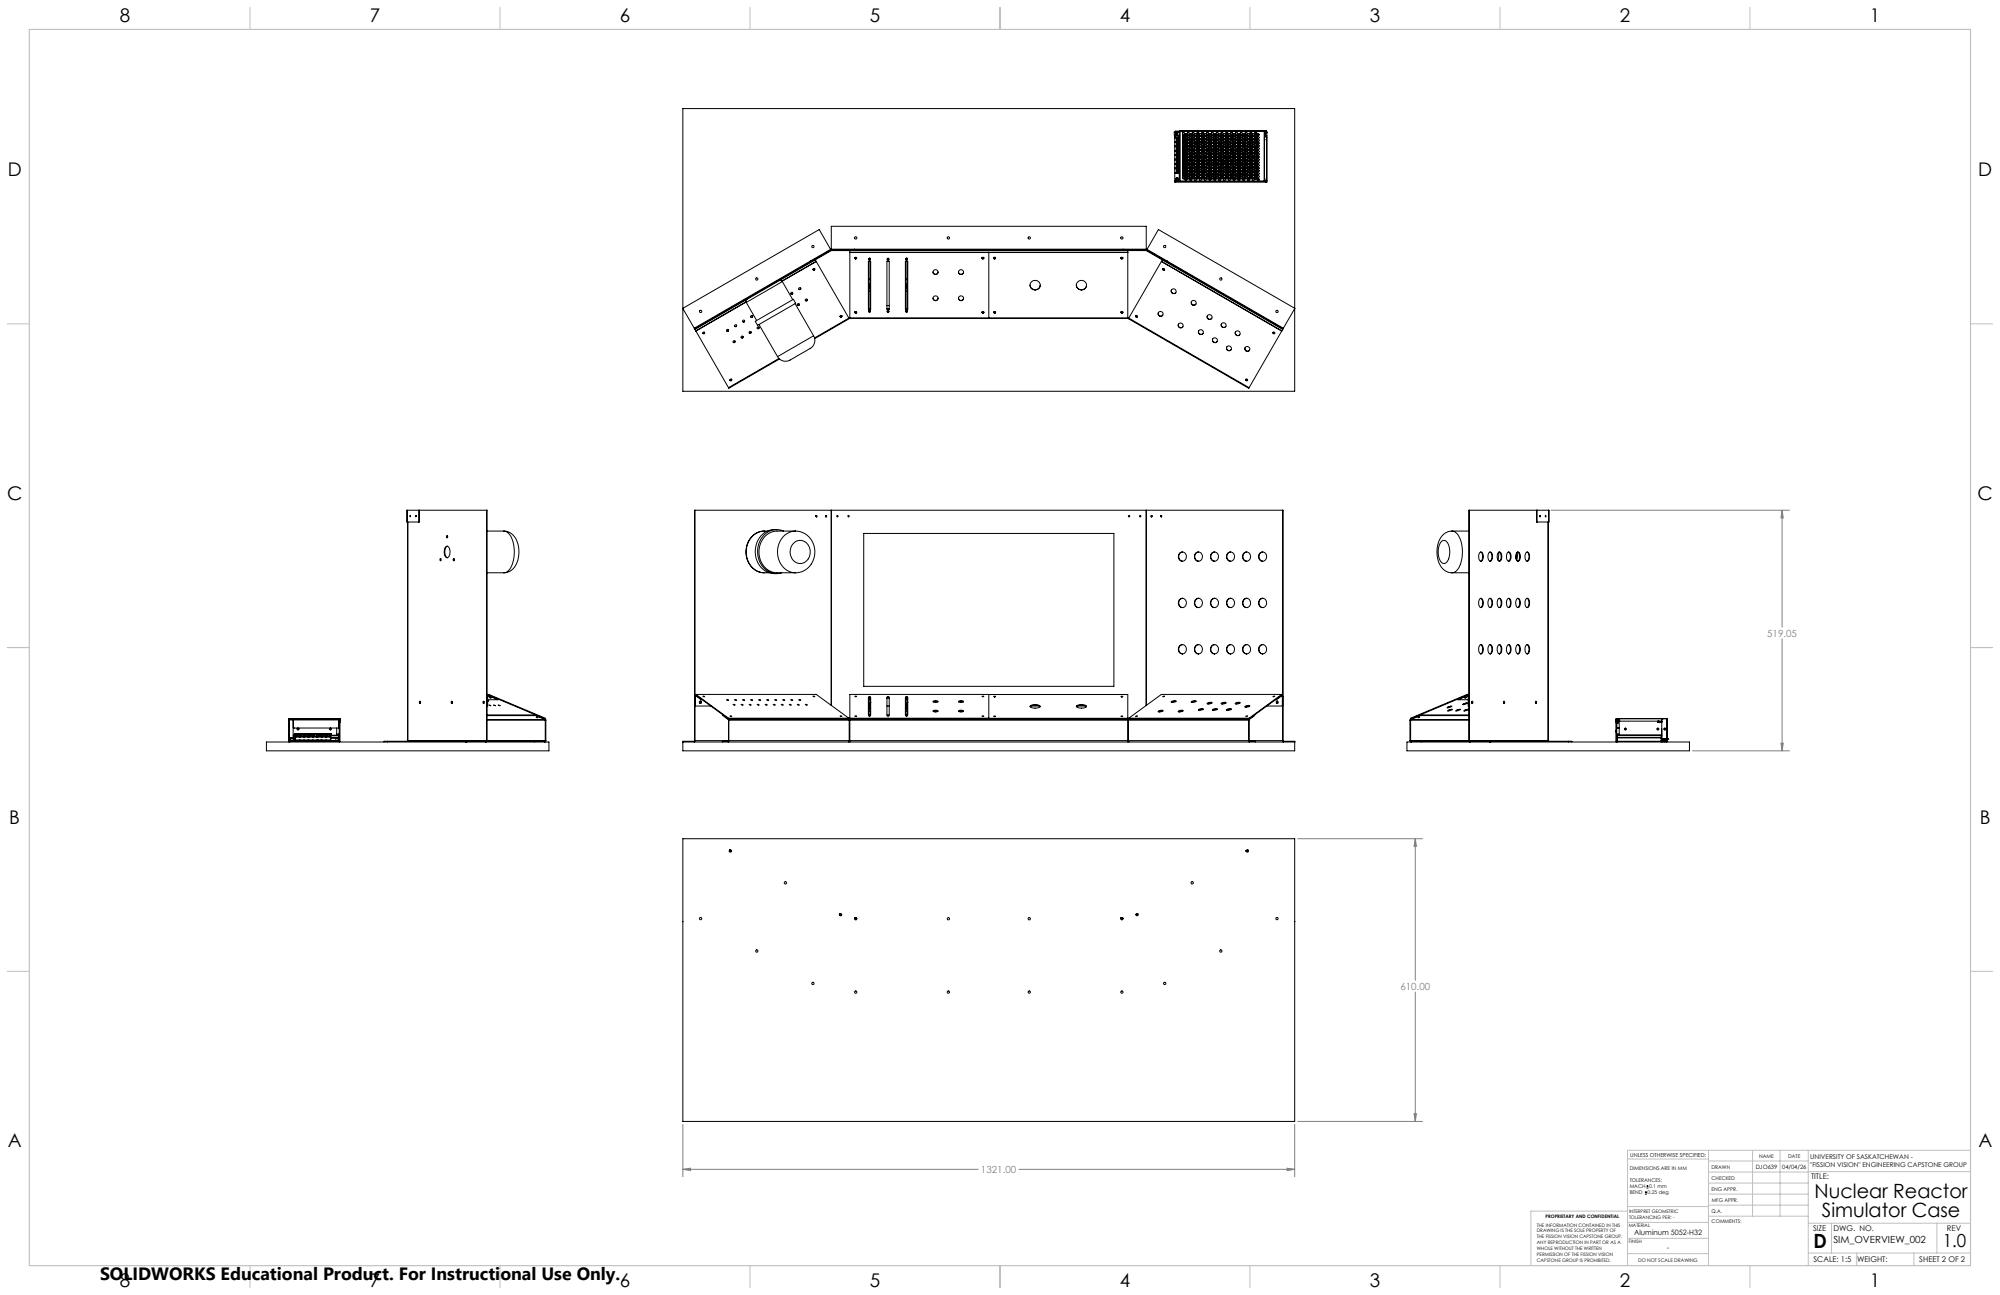
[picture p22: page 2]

UNLESS OTHERWISE SPECIFIED: | | NAME | DATE | UNIVERSITY OF SASKATCHEWAN -"FISSION VISION" ENGINEERING CAPSTONE GROUP
DIMENSIONS ARE IN MM TOLERANCES: MACH 0.1 mm | DRAWN | DJO639 | 04/04/26

CHECKED | | | TITLE: Nuclear Reactor

SIM_OVERVIEW_002

SCALE: 1:5 | WEIGHT:

3.00

3.00

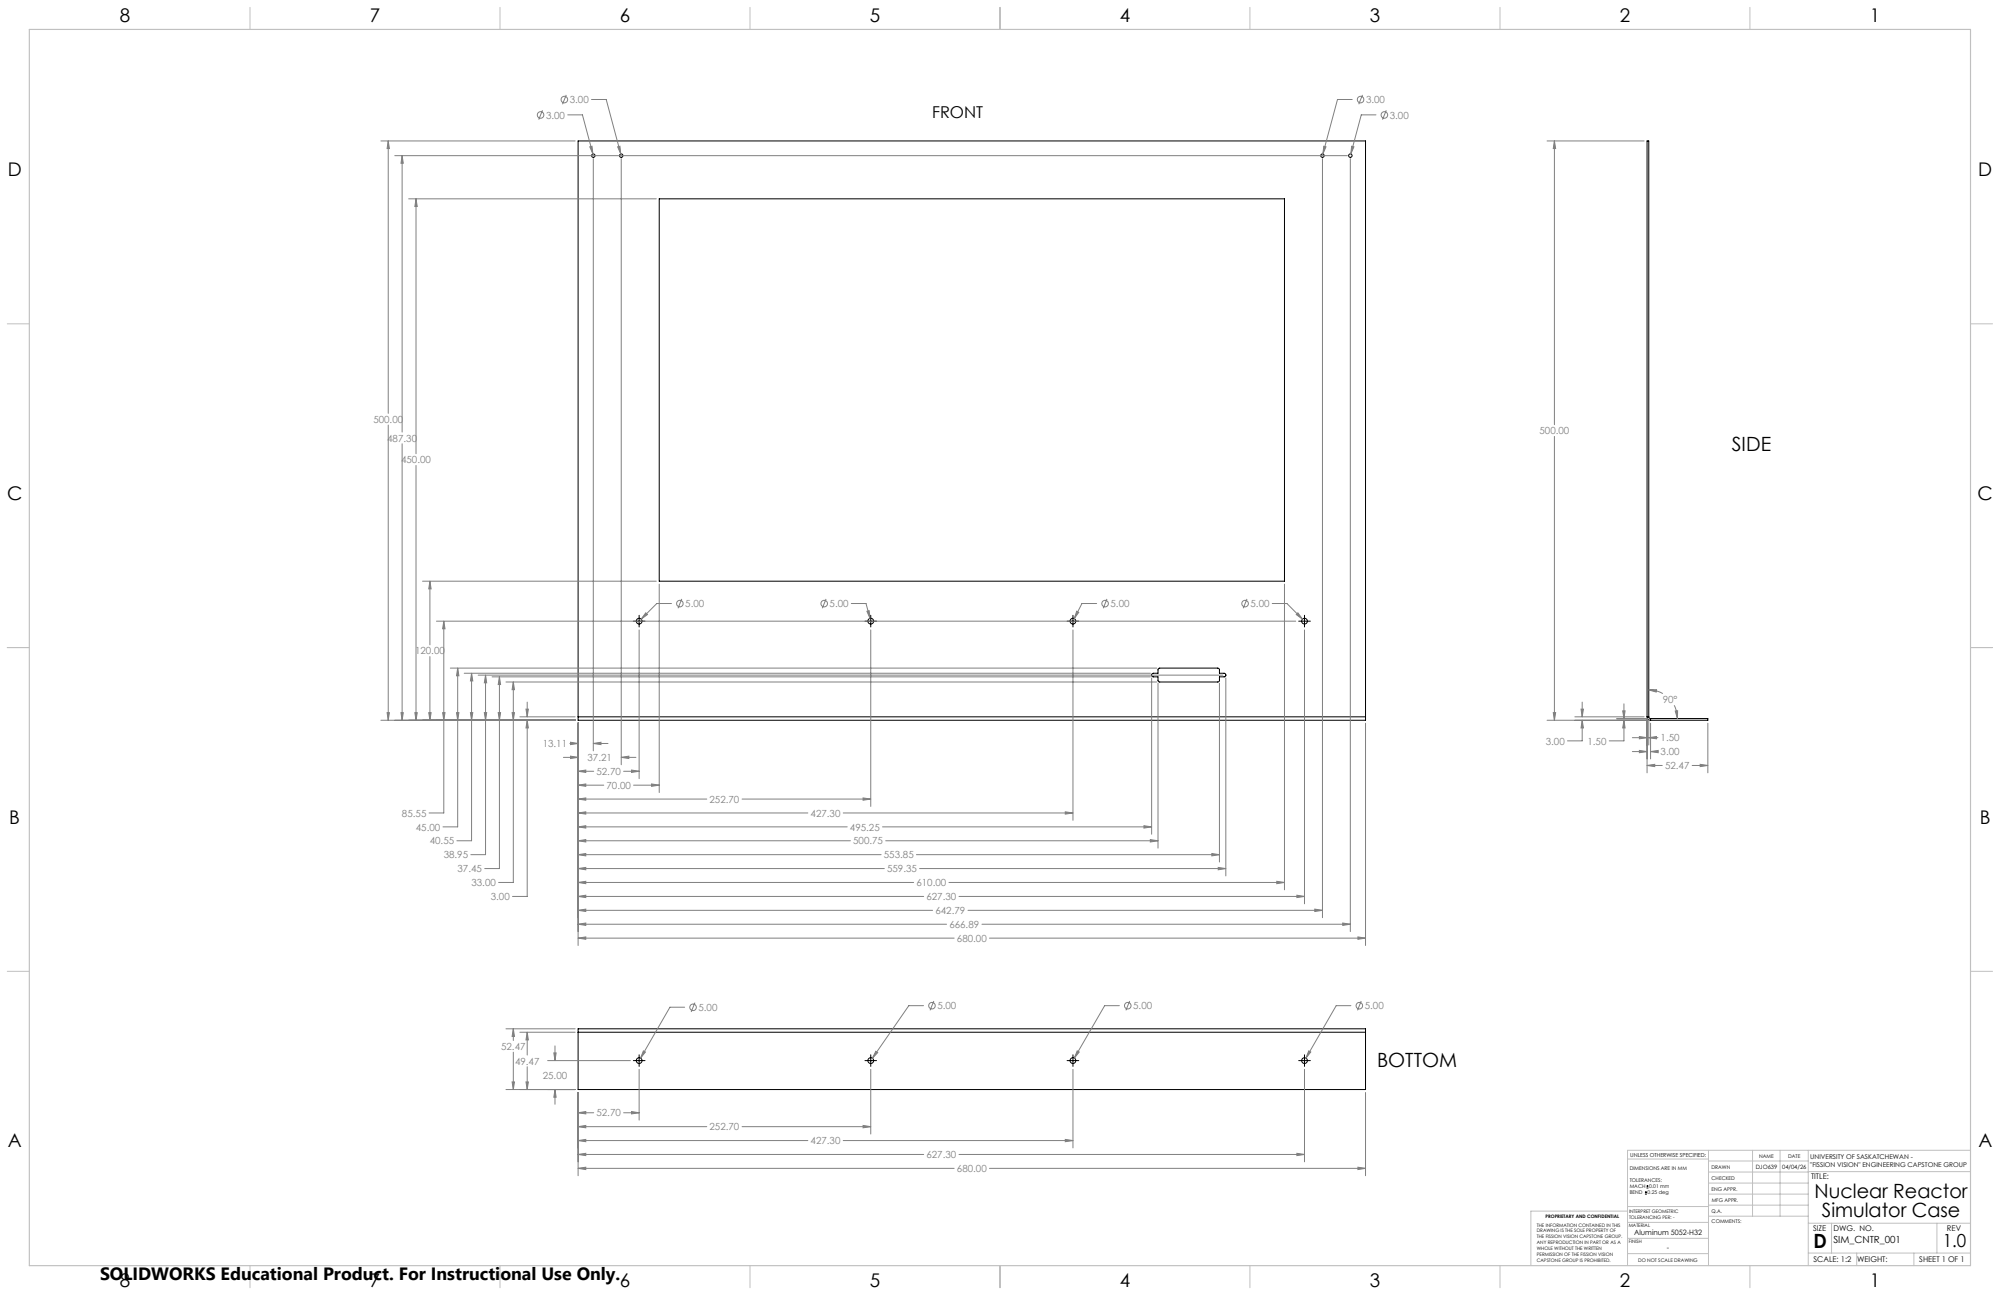
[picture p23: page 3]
FRONT; BOTTOM; SIDE

UNLESS OTHERWISE SPECIFIED: | | NAME | DATE | UNIVERSITY OF SASKATCHEWAN -"FISSION VISION" ENGINEERING CAPSTONE GROUP
DIMENSIONS ARE IN MM TOLERANCES: MACH 0.01 mm | DRAWN | DJO639 | 04/04/26

CHECKED | | | TITLE: Nuclear Reactor

SIM_CNTR_001

SCALE: 1:2 | WEIGHT:

3.0

3.0

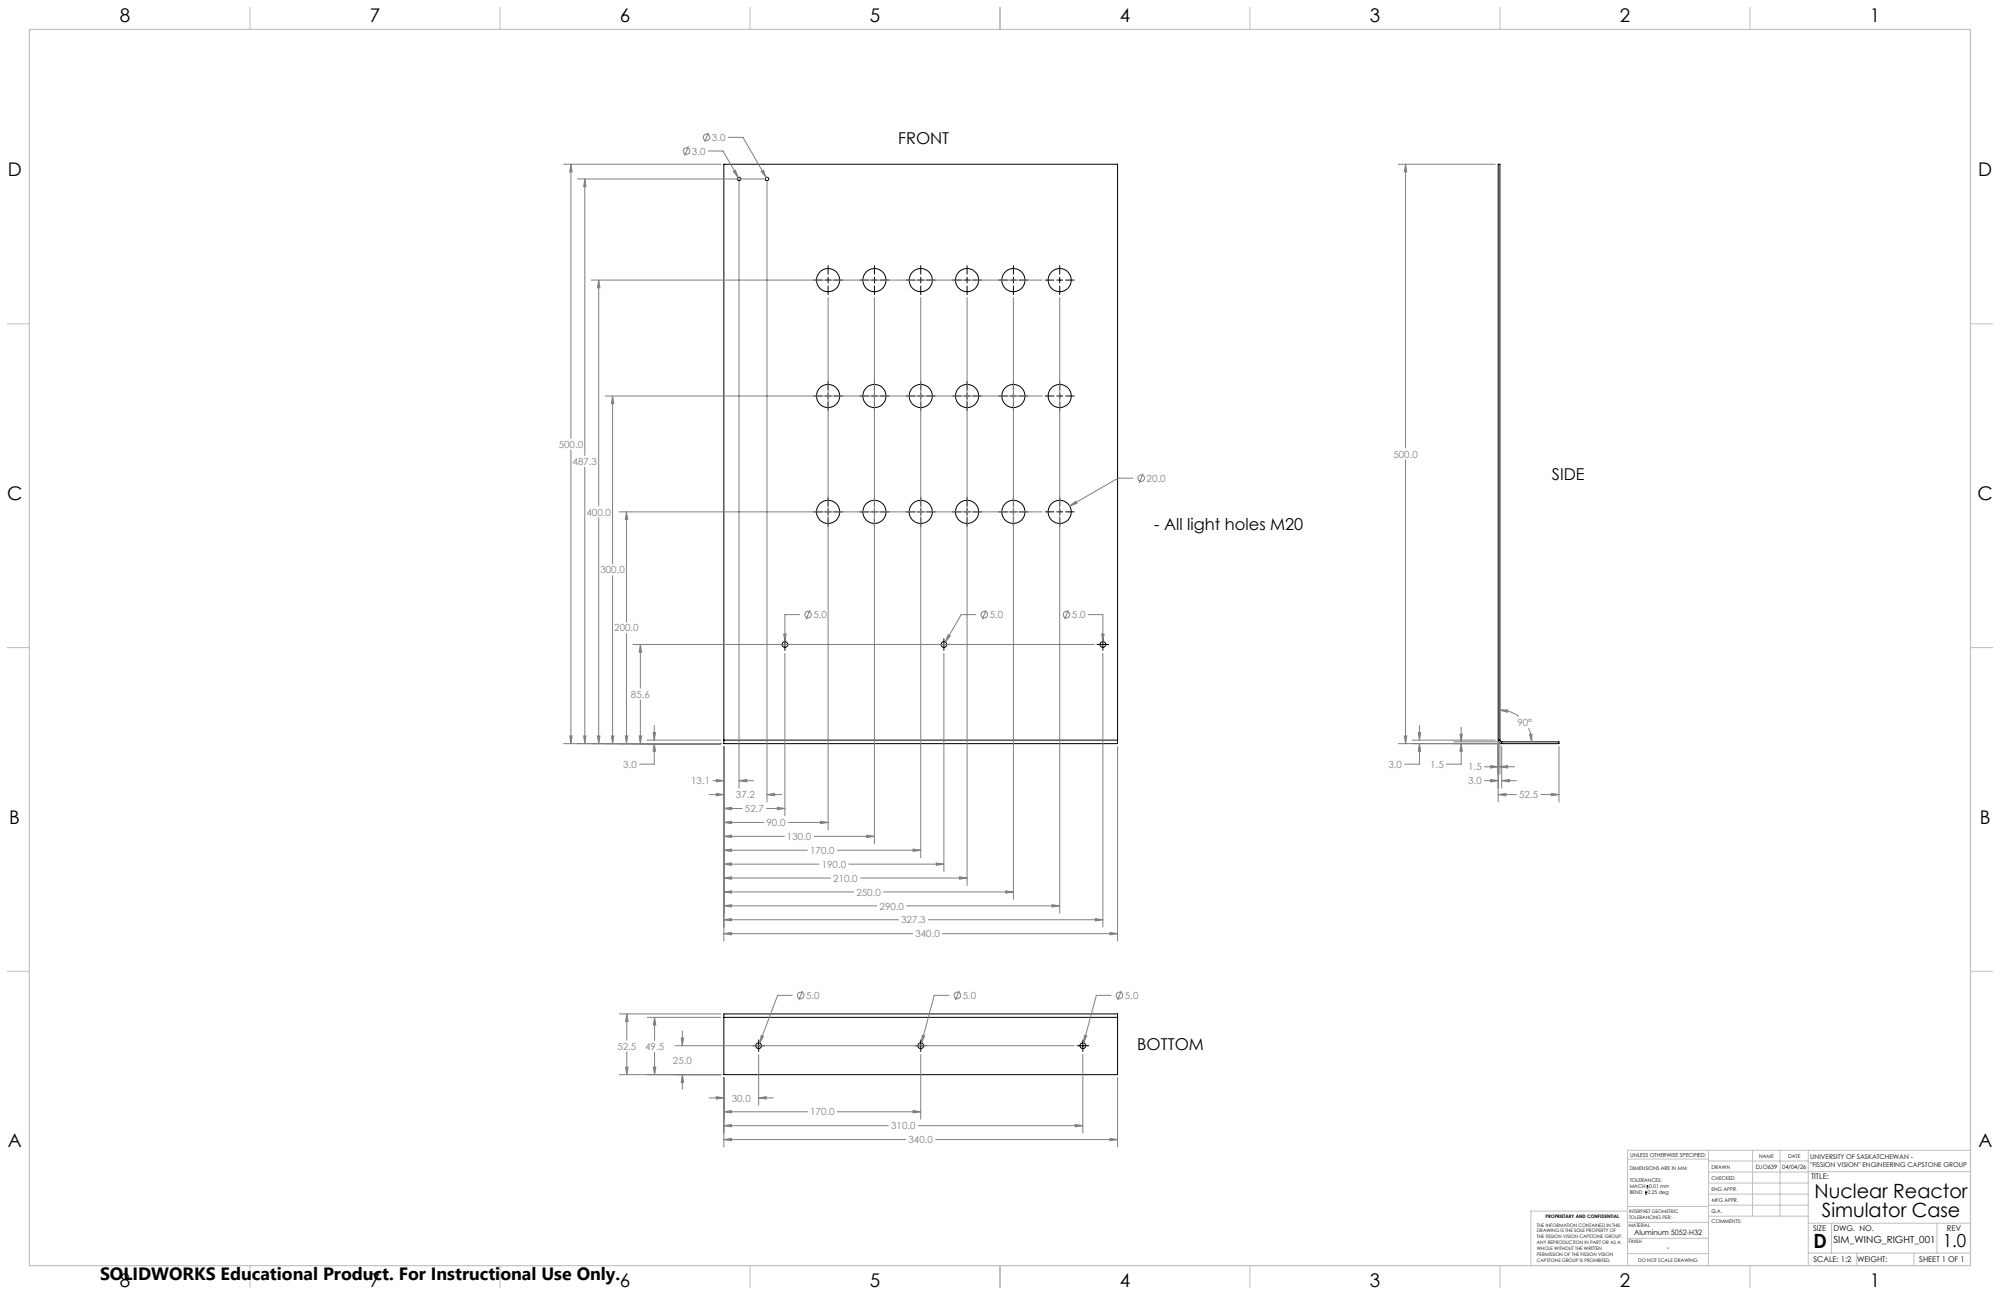
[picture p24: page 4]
FRONT; SIDE; BOTTOM

- All light holes M20

UNLESS OTHERWISE SPECIFIED: | | NAME | DATE | UNIVERSITY OF SASKATCHEWAN -"FISSION VISION" ENGINEERING CAPSTONE GROUP
DIMENSIONS ARE IN MM TOLERANCES: | DRAWN | DJO639 | 04/04/26

CHECKED | | | TITLE: Nuclear Reactor

SIM_WING_RIGHT_001

SCALE: 1:2 | WEIGHT:

3.00
3.00

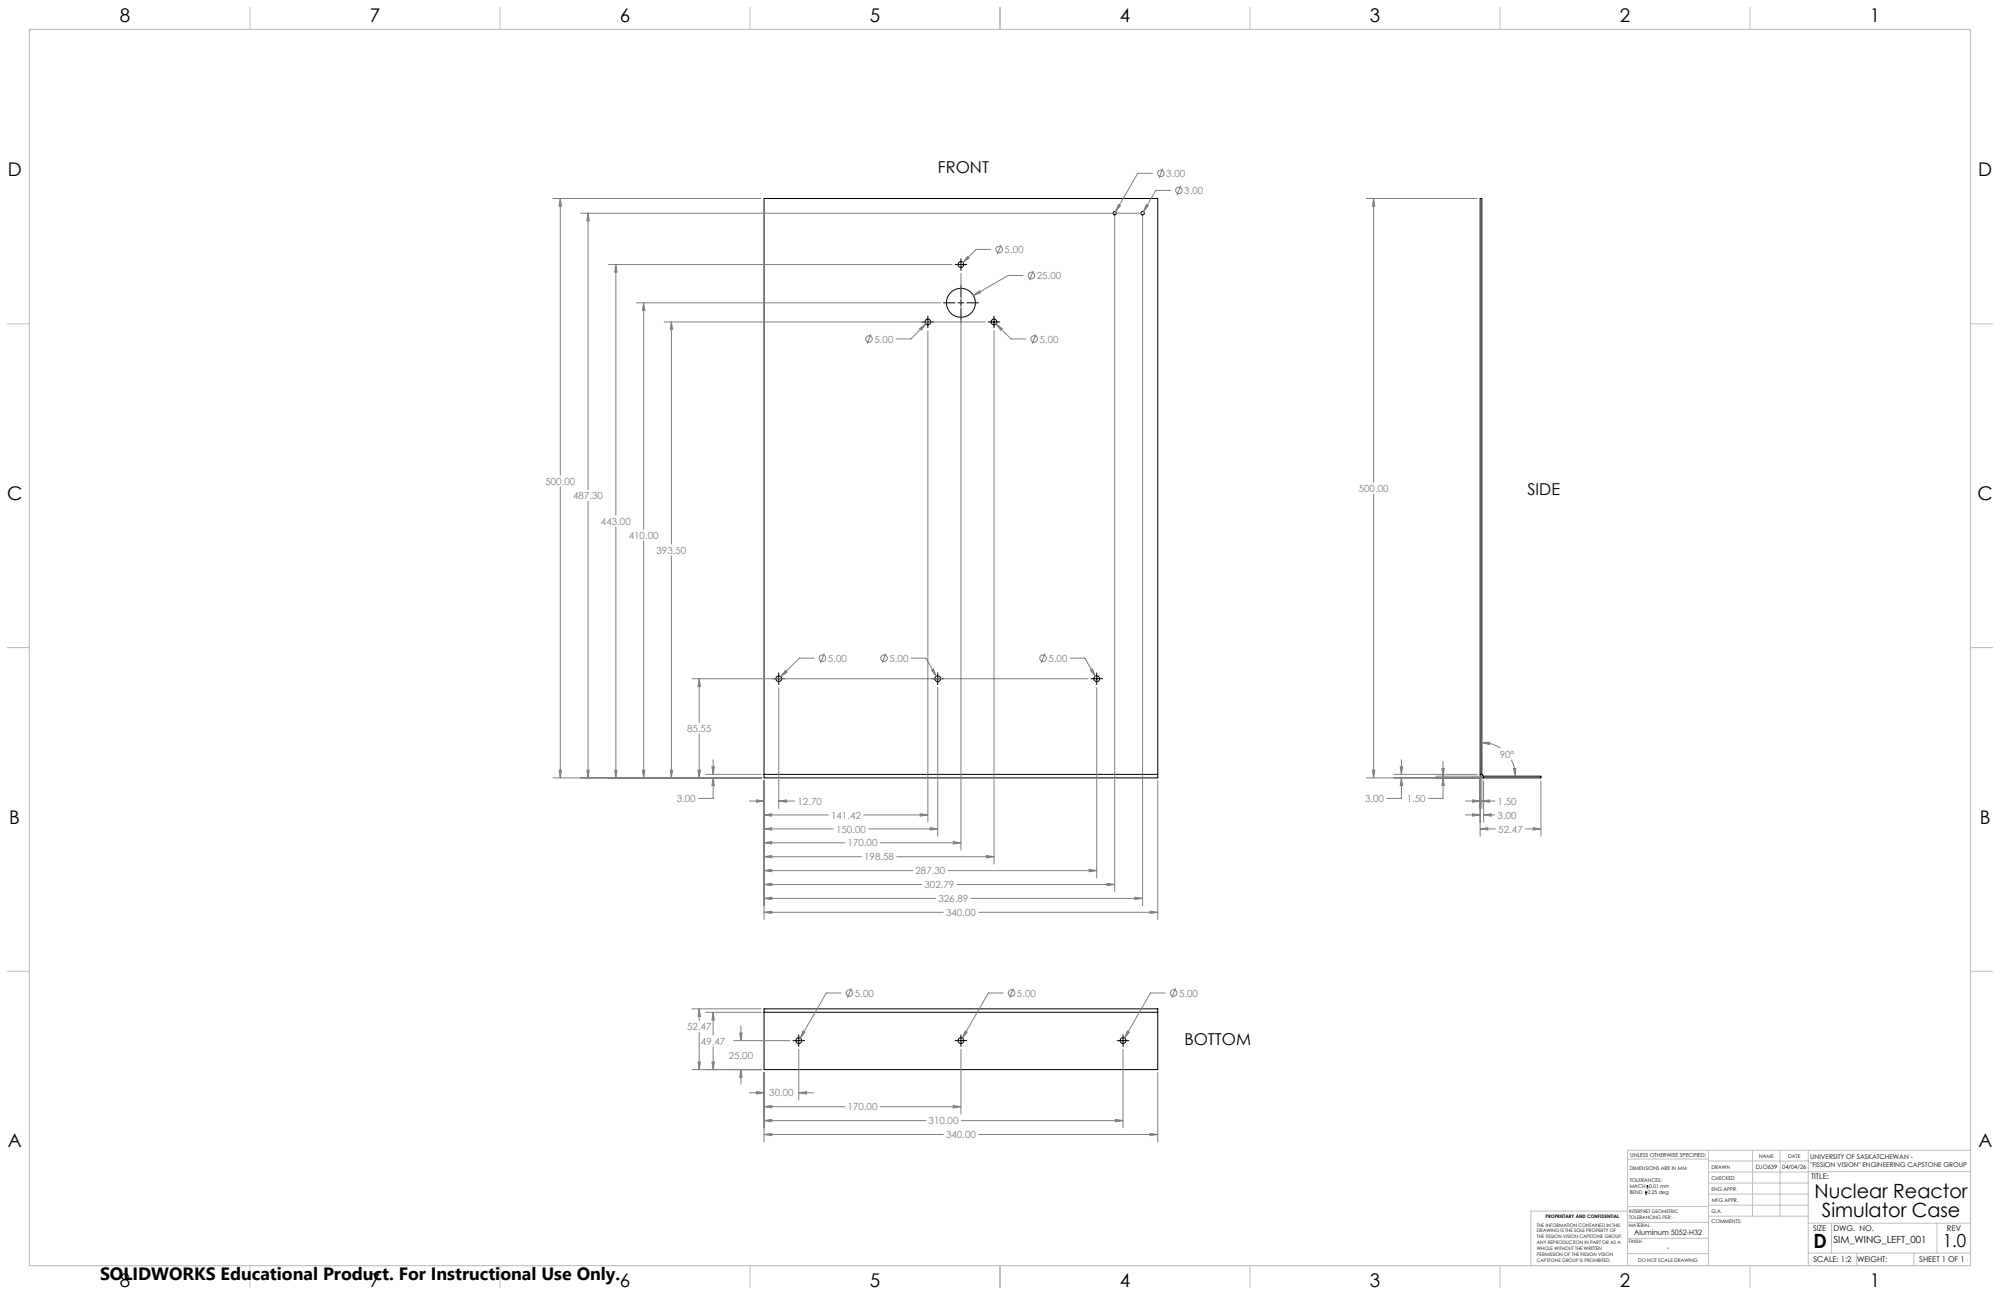
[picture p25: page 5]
FRONT; SIDE; BOTTOM

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

CHECKED | | | TITLE: Nuclear Reactor

SIM_WING_LEFT_001

SCALE: 1:2 | WEIGHT:

D | D

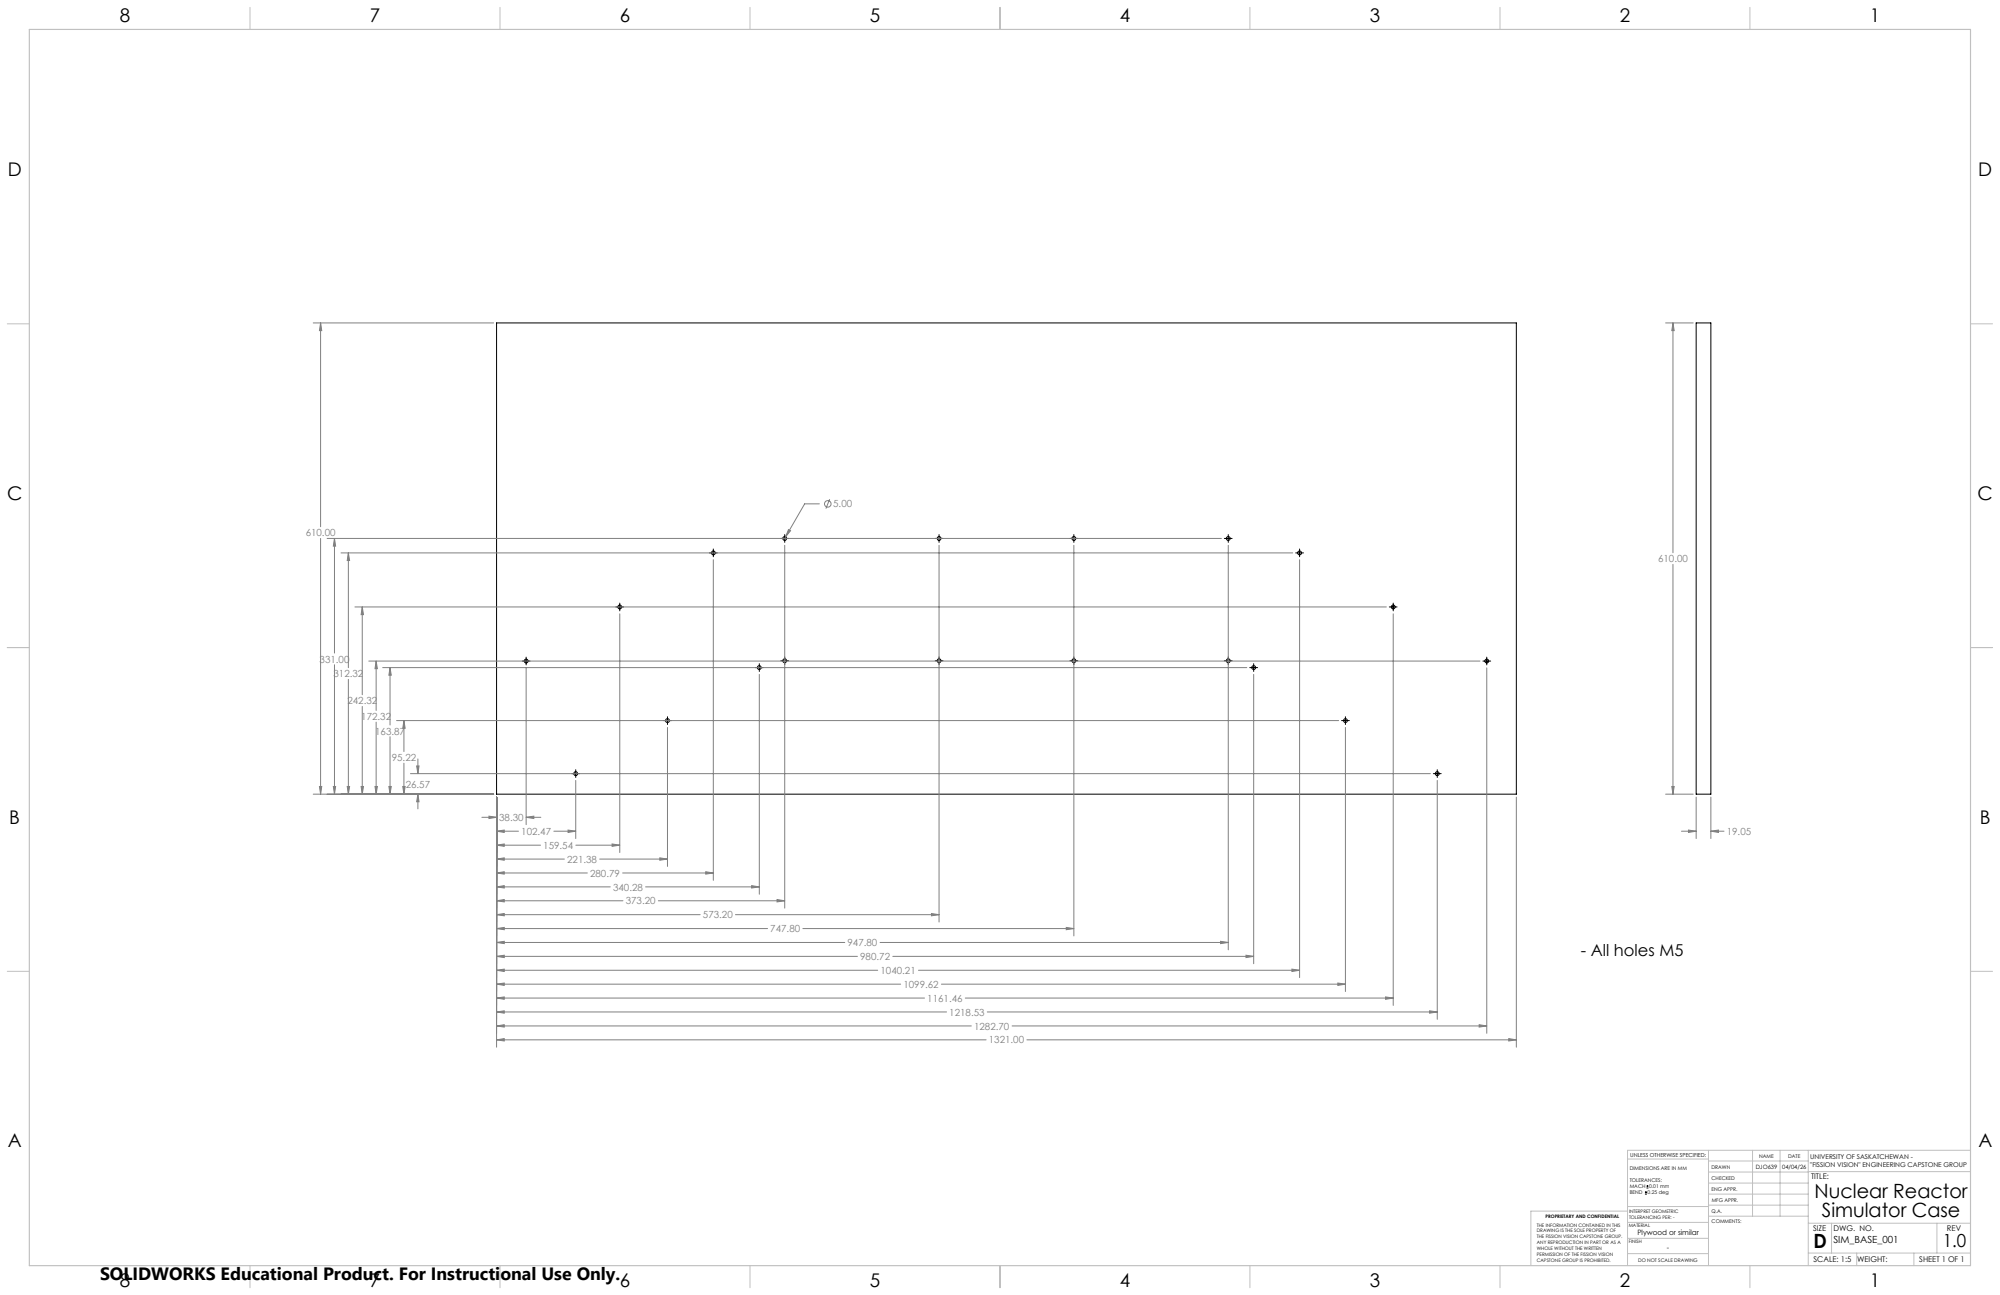
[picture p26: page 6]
- All holes M5; SCALE: 1:5; WEIGHT:; SIM_BASE_001

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

CHECKED | | | TITLE: Nuclear Reactor

Plywood or similar

4.00 | 4.60

# SAFETY ENABLED

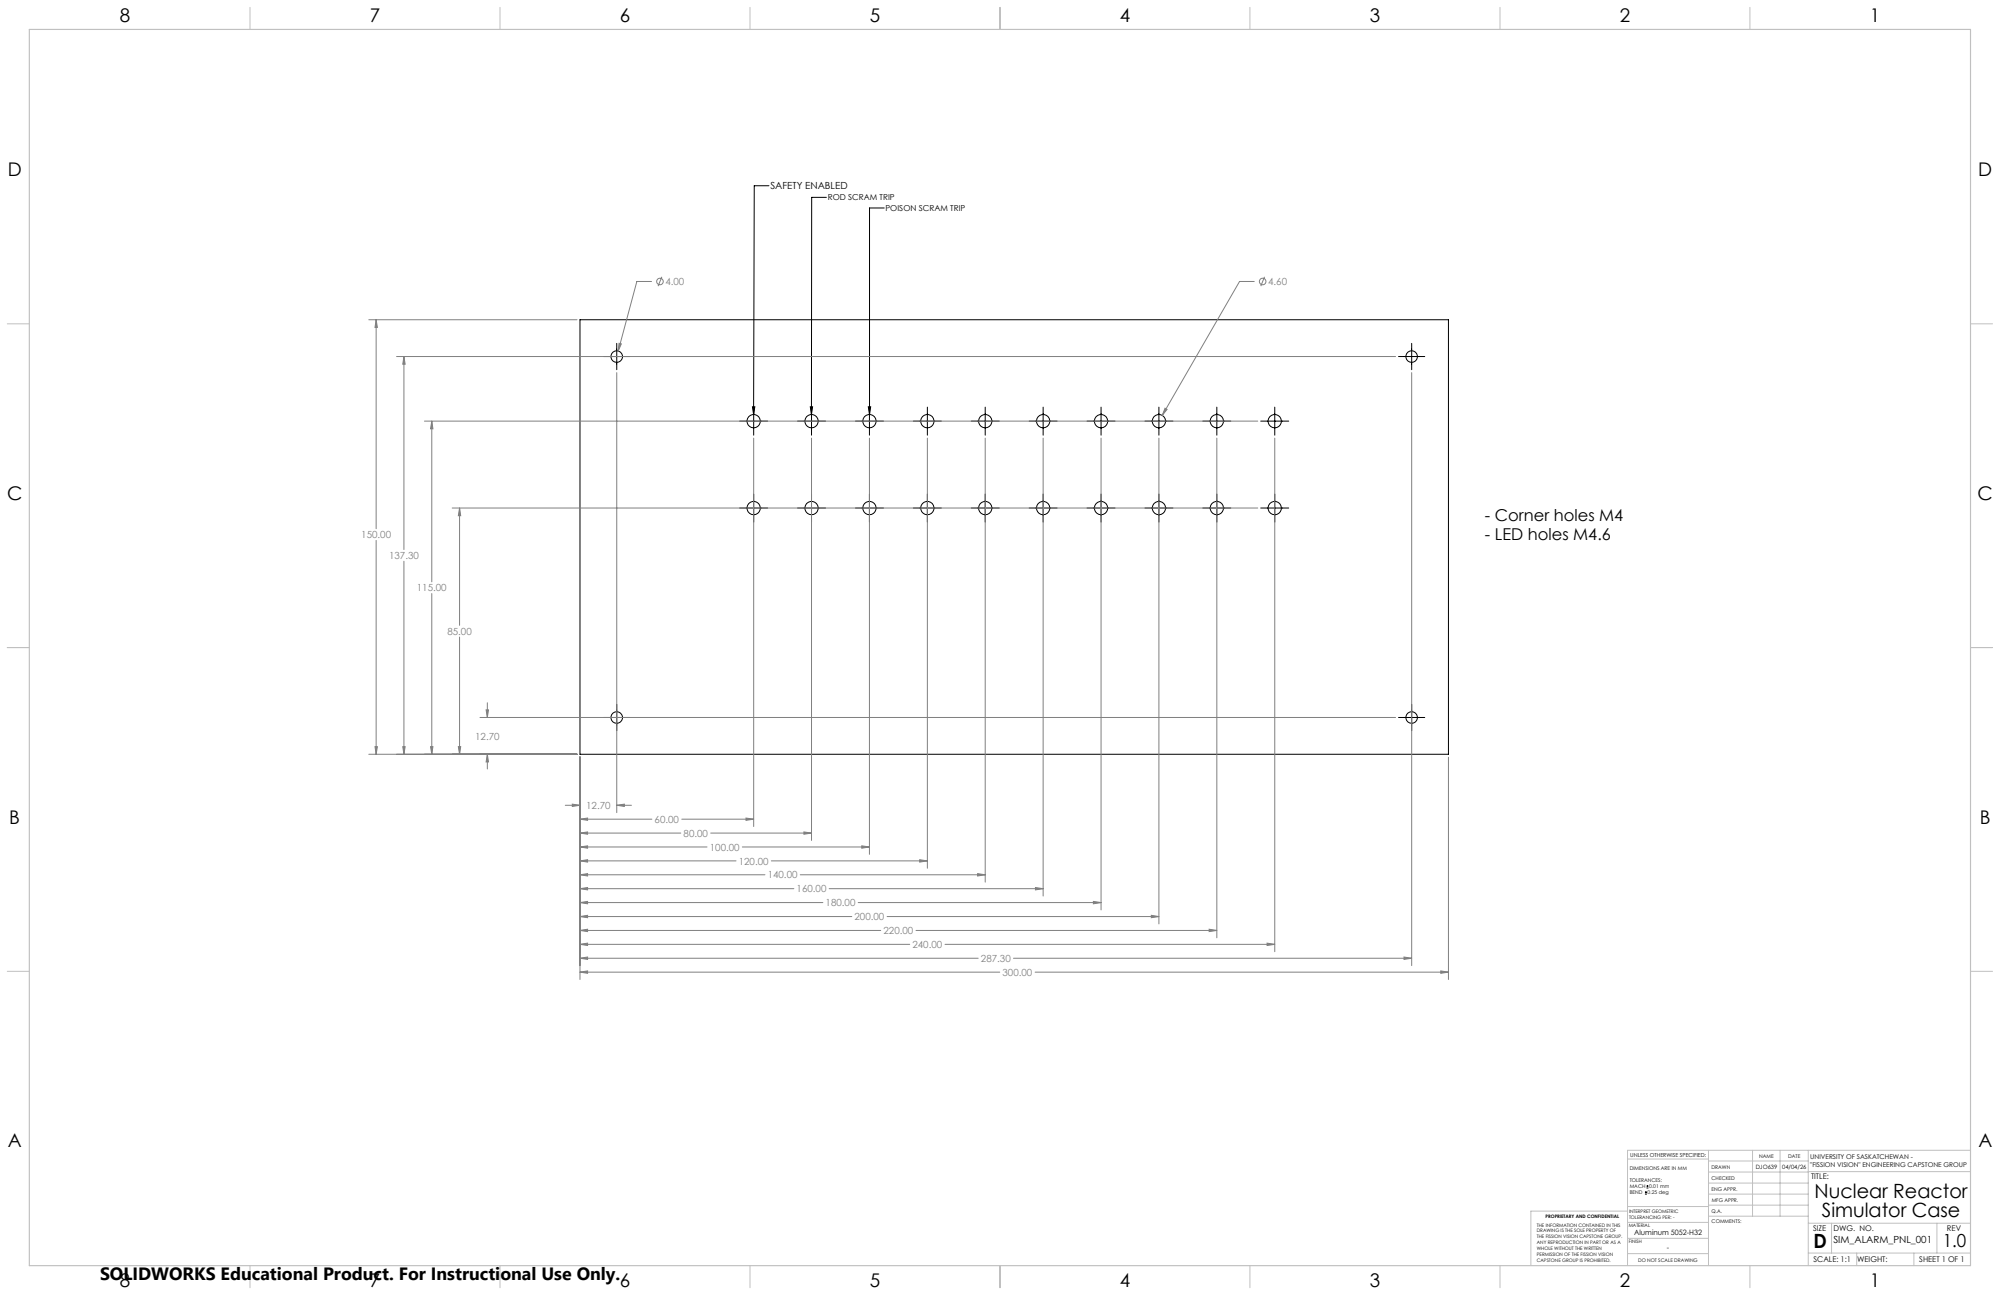
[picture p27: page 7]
- Corner holes M4 - LED holes M4.6

ROD SCRAM TRIP

POISON SCRAM TRIP

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

CHECKED | | | TITLE: Nuclear Reactor

SIM_ALARM_PNL_001

SCALE: 1:1 | WEIGHT:

4.00 | 4.00 | 11.00
D | D

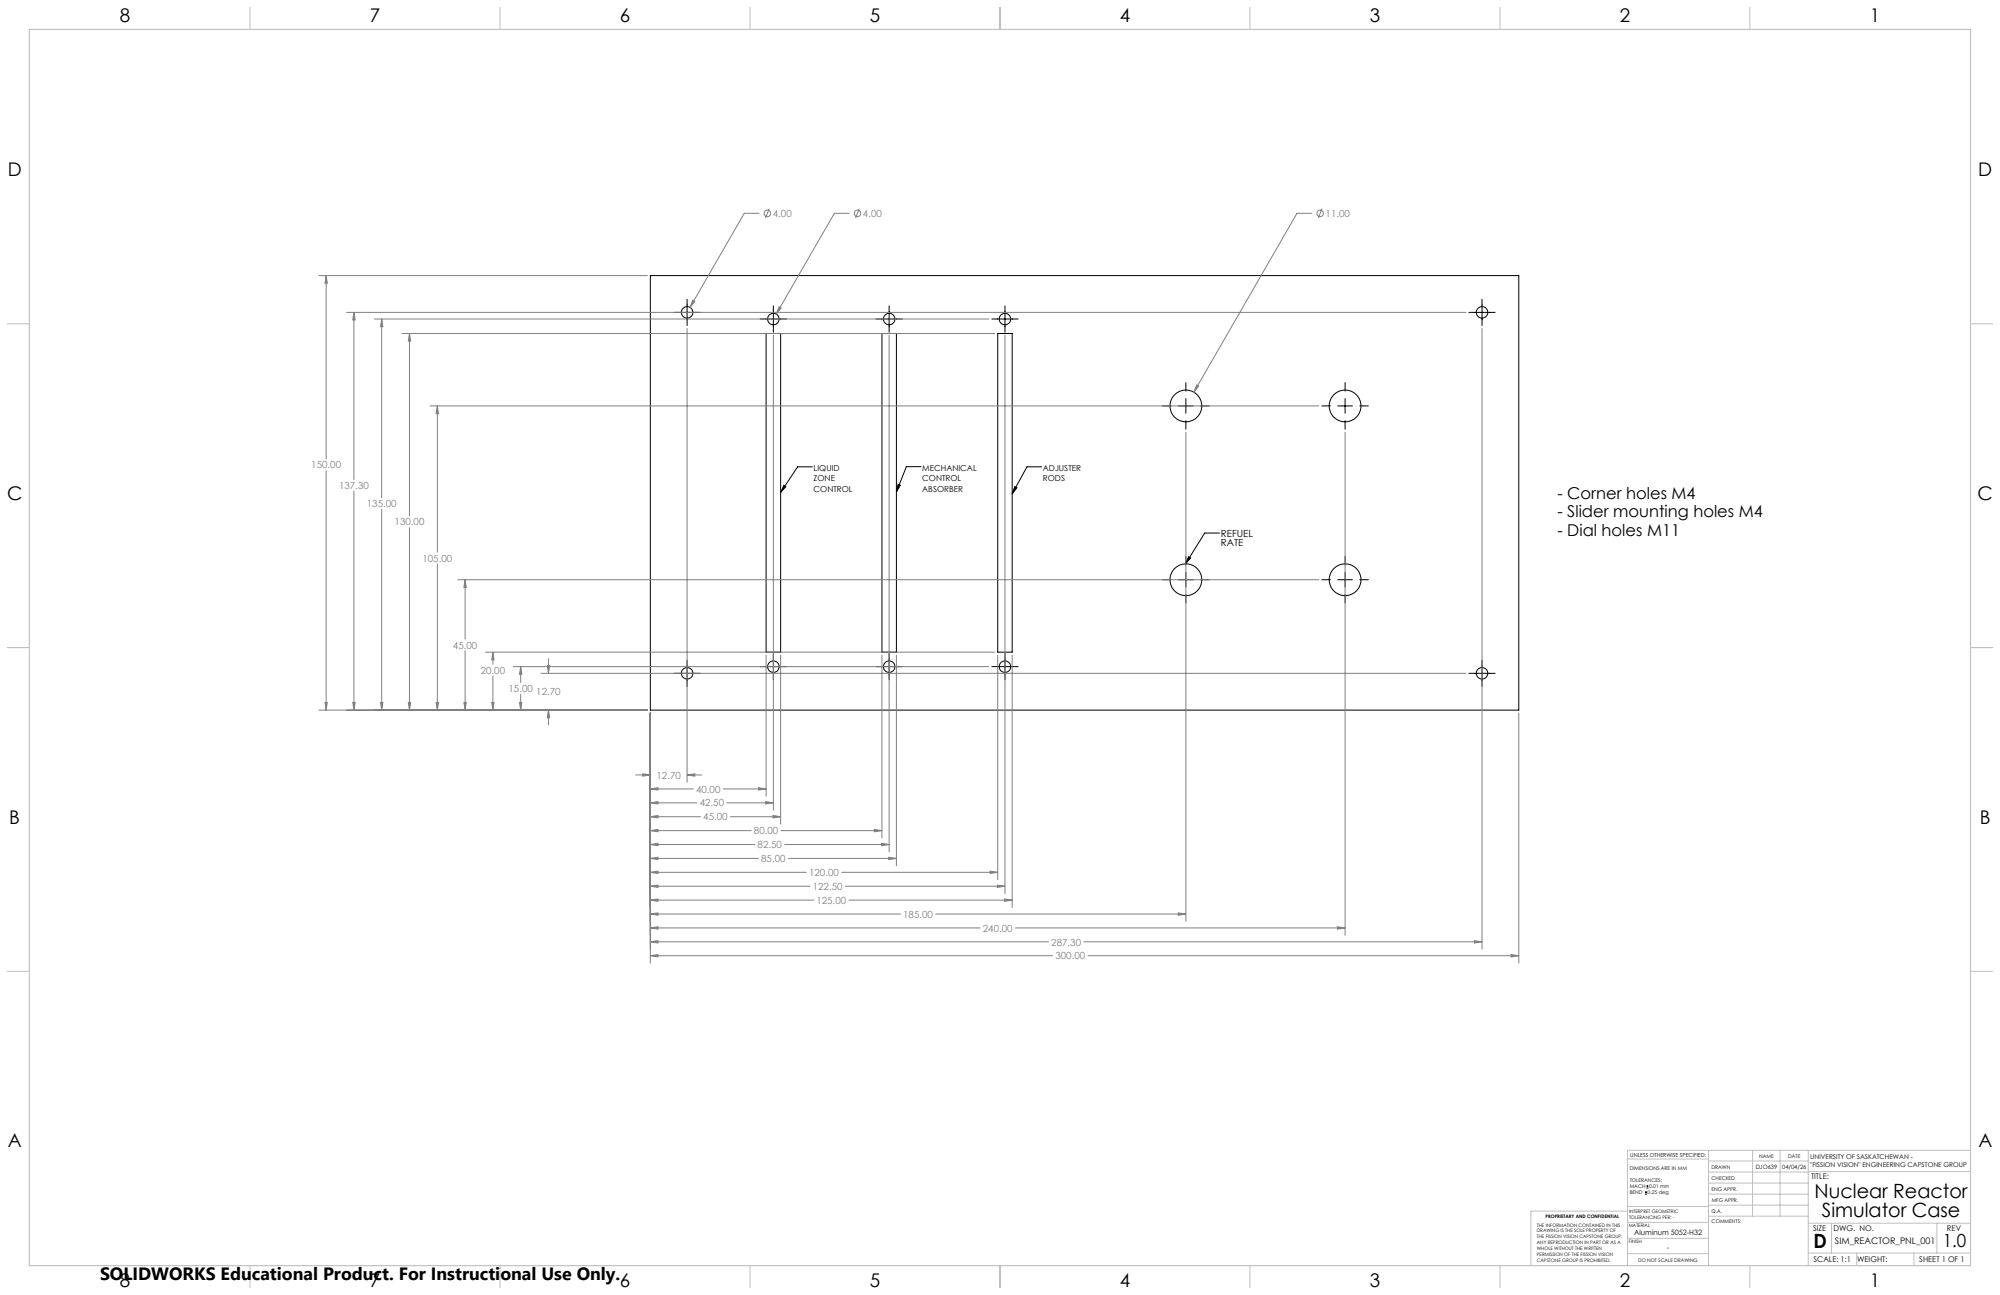
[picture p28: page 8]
LIQUID ZONE CONTROL; MECHANICAL CONTROL ABSORBER; ADJUSTER RODS; REFUEL RATE; SIM_REACTOR_PNL_001

- Corner holes M4
- Slider mounting holes M4
- Dial holes M11

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

CHECKED | | | TITLE: Nuclear Reactor

4.00
22.00

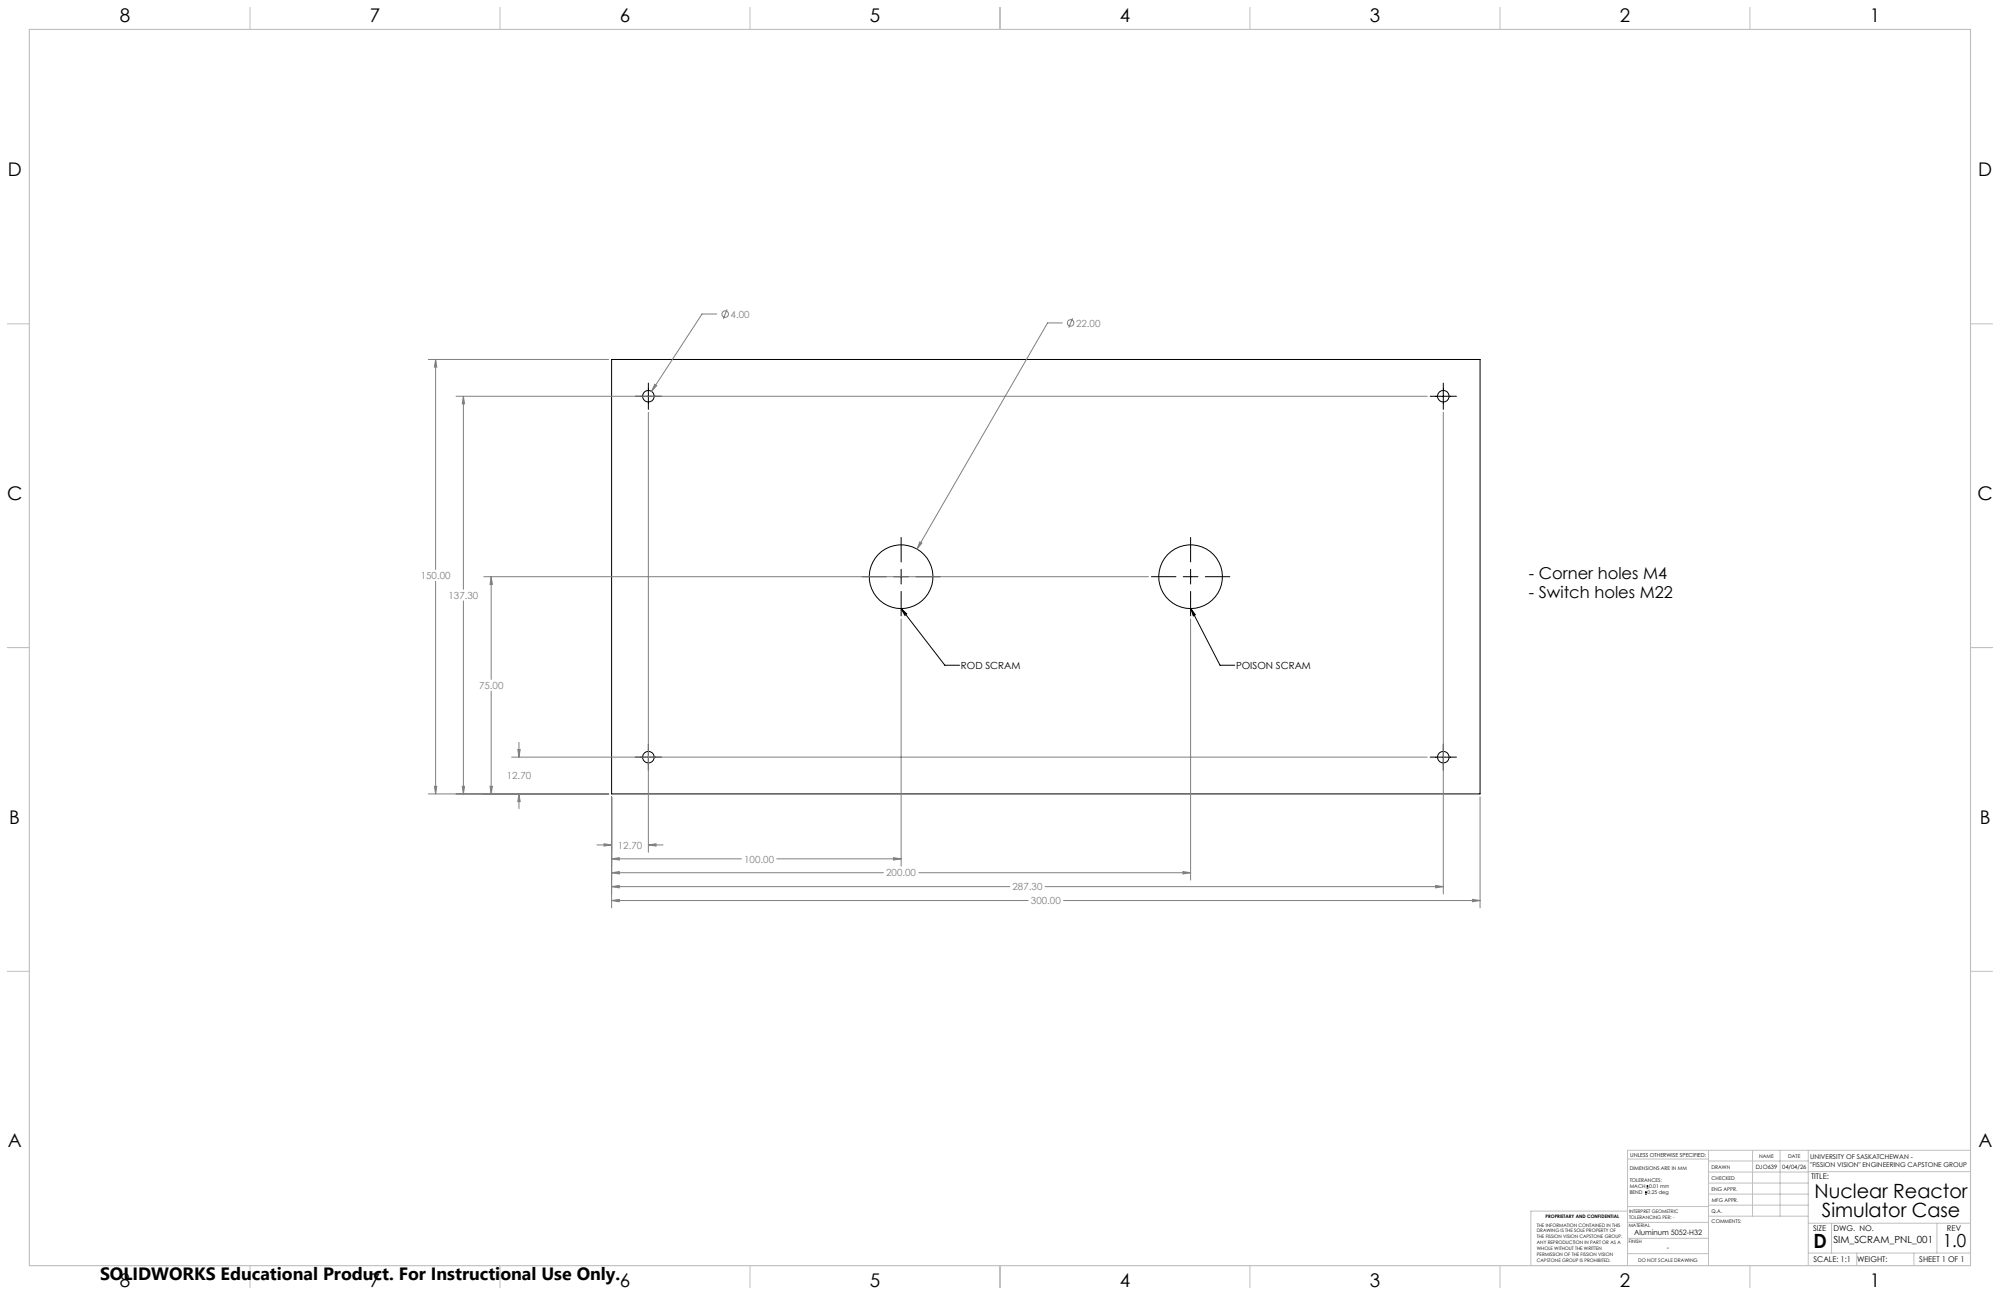
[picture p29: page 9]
- Corner holes M4 - Switch holes M22; ROD SCRAM; POISON SCRAM; SIM_SCRAM_PNL_001

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

CHECKED | | | TITLE: Nuclear Reactor

4.00 | 11.00
D | D

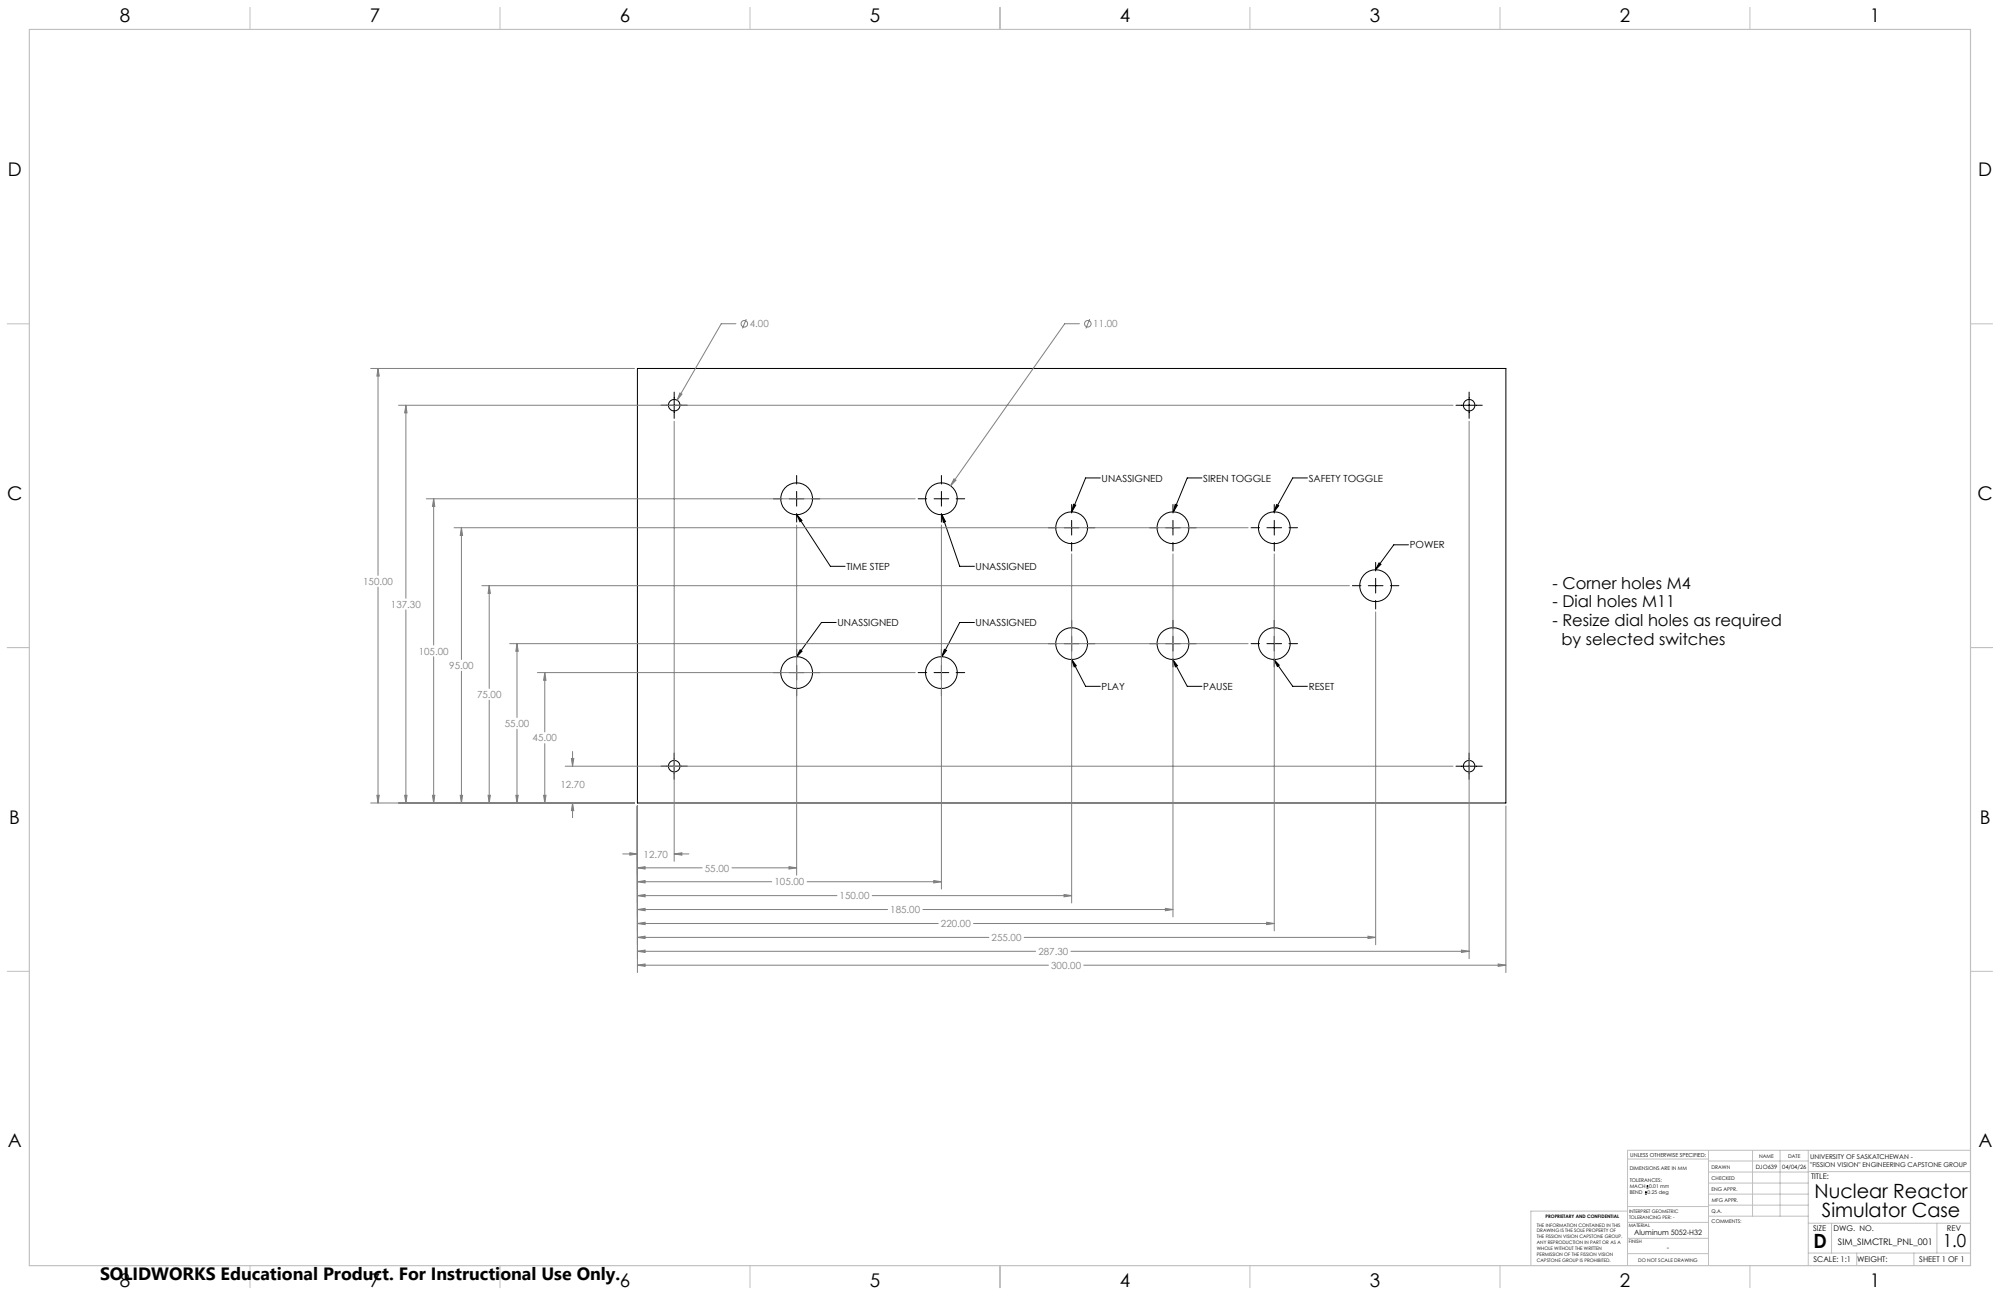
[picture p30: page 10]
POWER; PLAY; PAUSE; RESET; UNASSIGNED; SIREN TOGGLE; SAFETY TOGGLE; TIME STEP; SIM_SIMCTRL_PNL_001

- Corner holes M4
- Dial holes M11
- Resize dial holes as required
by selected switches

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

CHECKED | | | TITLE: Nuclear Reactor

5.00

4.00

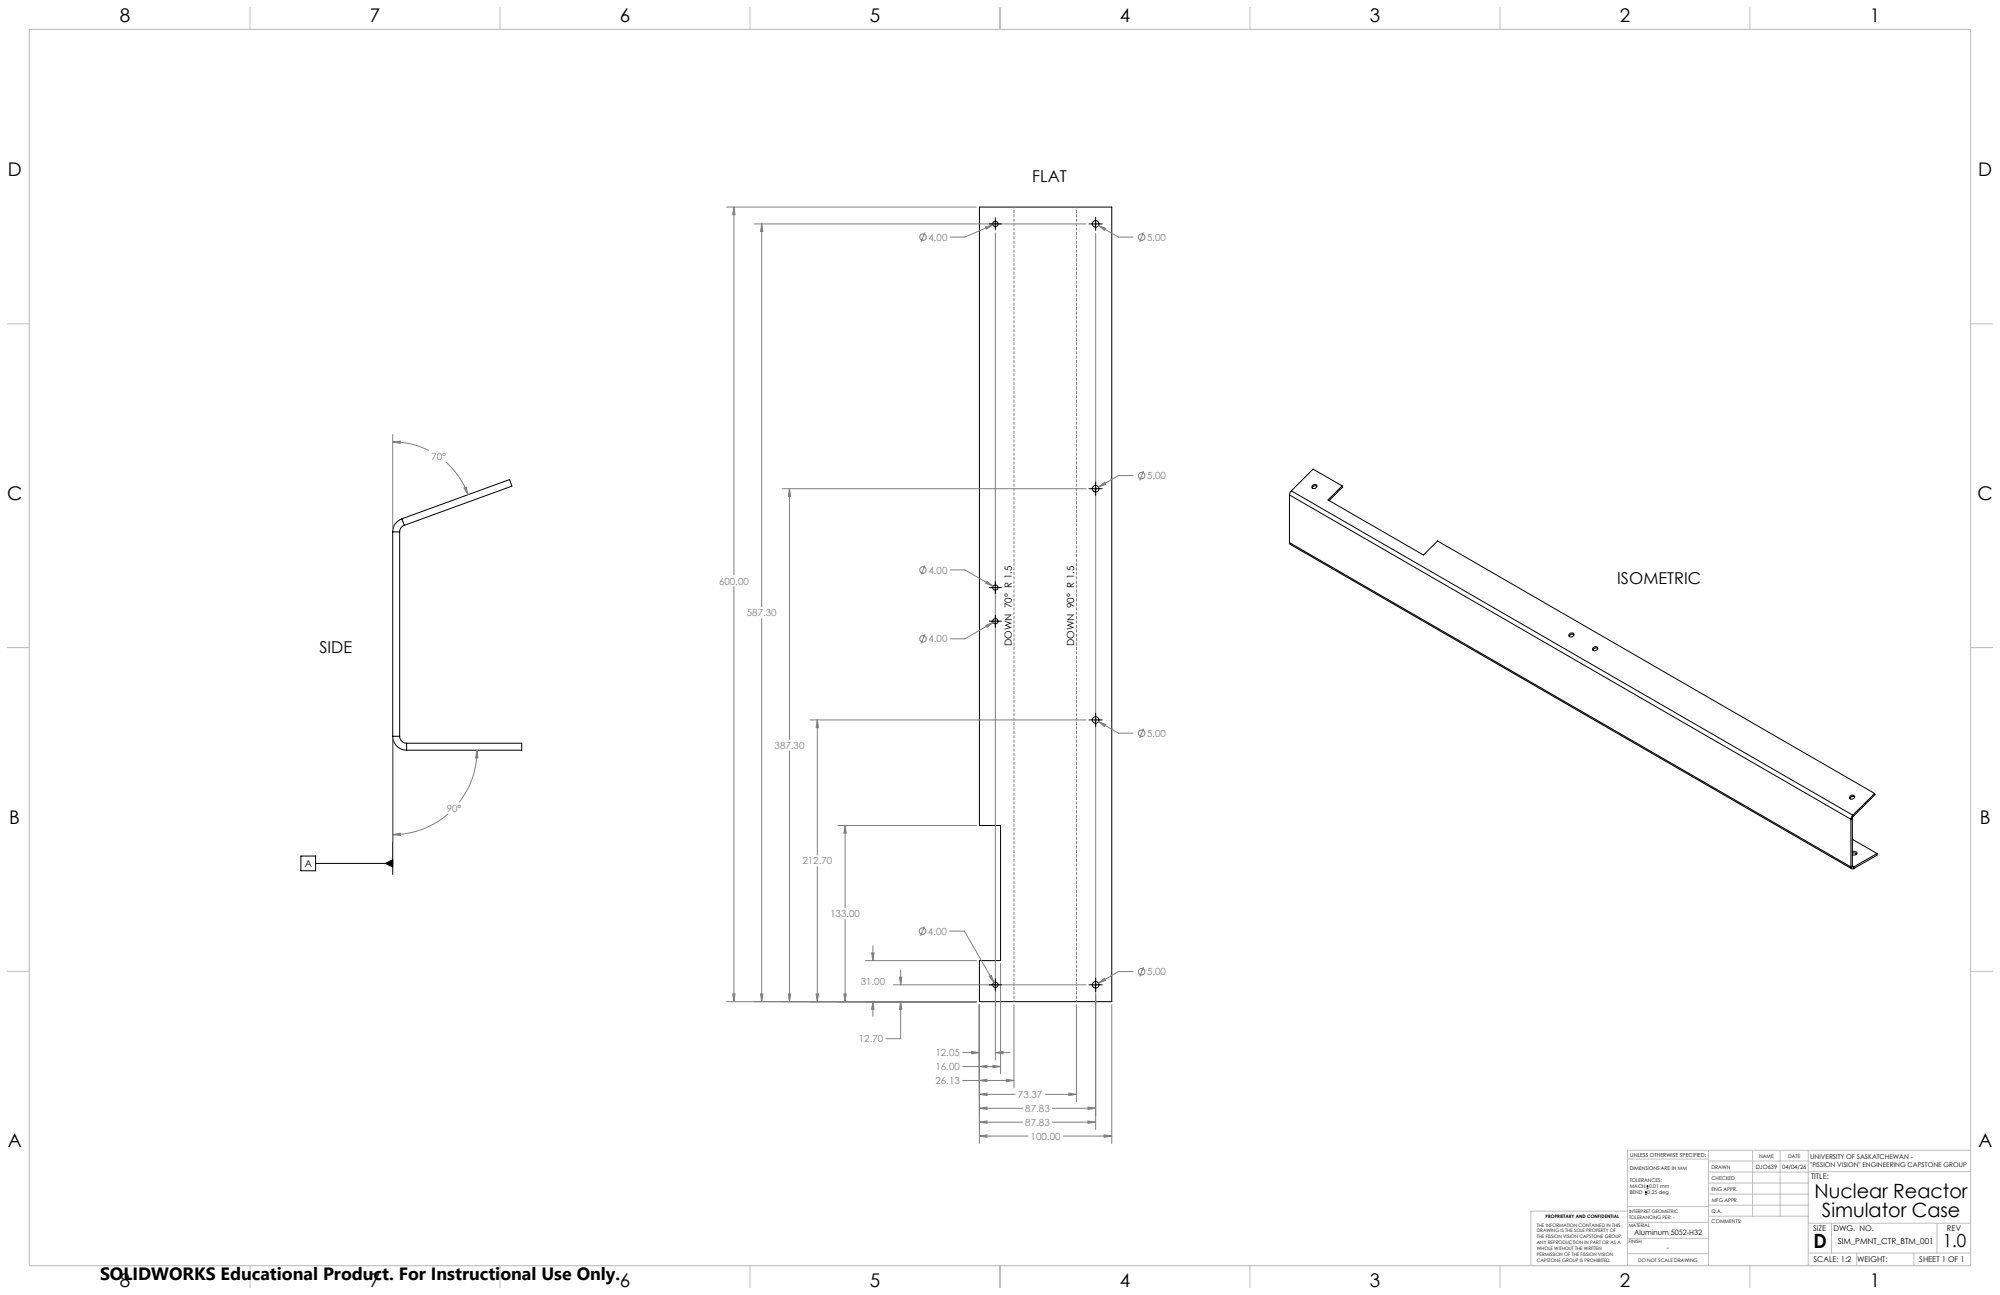
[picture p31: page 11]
DOWN 70° R 1.5; DOWN 90° R 1.5; FLAT; SIDE; ISOMETRIC

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

CHECKED | | | TITLE: Nuclear Reactor

SIM_PMNT_CTR_BTM_001
SCALE: 1:2 | WEIGHT:

5.00

4.00

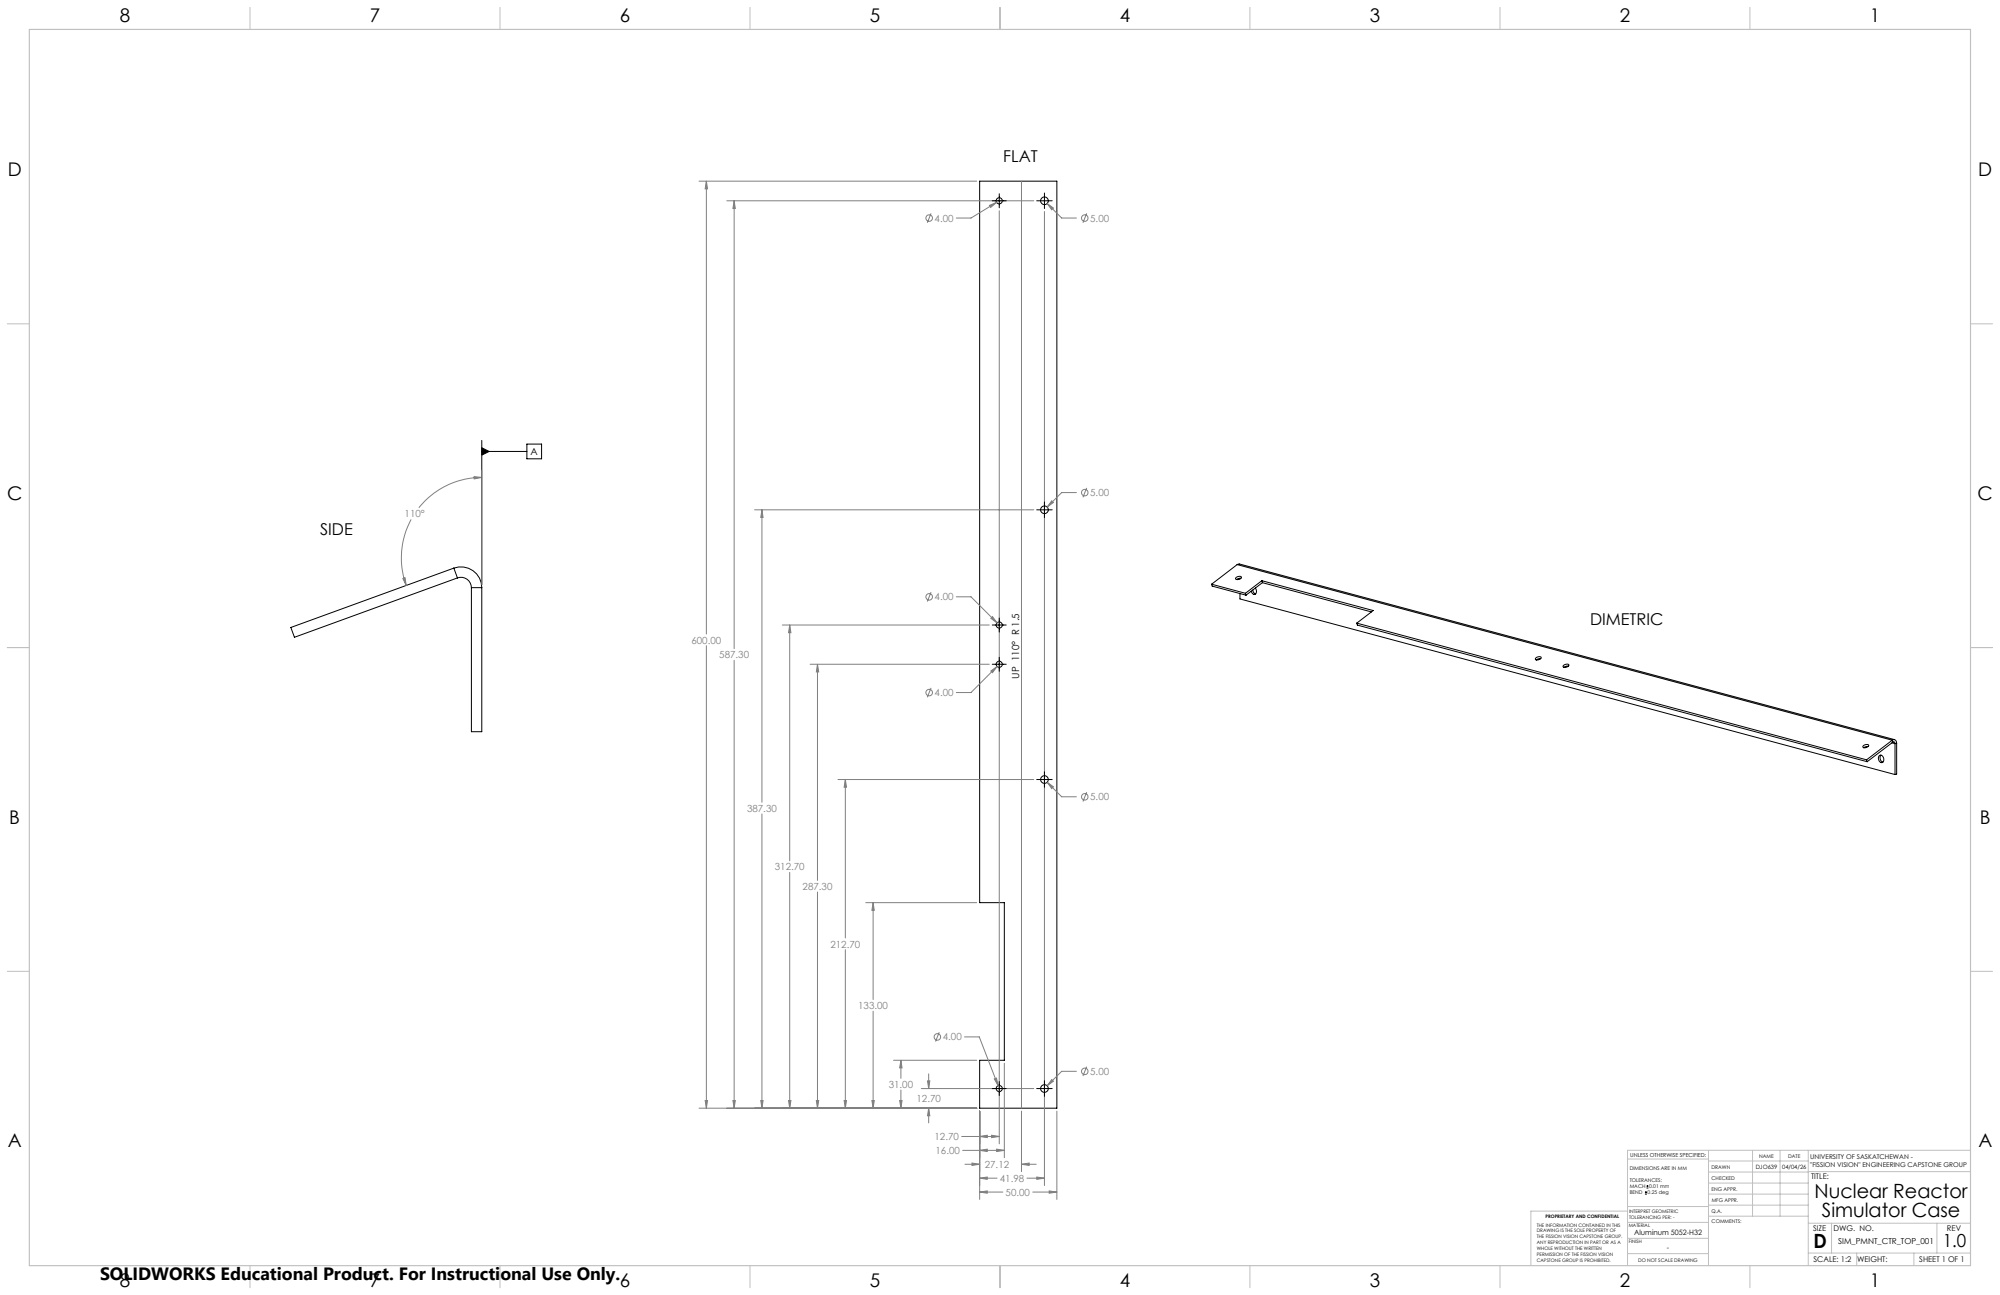
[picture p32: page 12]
FLAT; SIDE; DIMETRIC
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

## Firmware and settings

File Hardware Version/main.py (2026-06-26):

"""
Hardware-Integrated CANDU Reactor Simulator GUI
-----------------------------------------------

PyQt6 GUI for operating a real-time CANDU reactor simulation integrated
with physical control hardware via Raspberry Pi GPIO, ADC, and DAC modules.

Features:
    - Real-time reactor simulation visualization
    - Hardware potentiometer/switch input sampling
    - DAC analog outputs for physical gauges/lights
    - GPIO event-driven button handling
    - Reactor safety system simulation and siren control

Author: Adrienne Kolkman
Last Edited: March 23, 2026
"""

from PyQt6.QtWidgets import (
    QApplication, QMainWindow
)
from PyQt6.QtCore import QTimer
from PyQt6.uic import loadUi

import numpy as np
import pyqtgraph as pg
from candu_realtime_sim import CanduRealtimeSim, PlantParams
import time
import ADS1256
import DAC8532
import RPi.GPIO as GPIO
import pinouts

class MainGUIWindow(QMainWindow):
    """
    Main GUI window for the hardware-integrated reactor simulator.

    Manages:
        - Real-time simulation backend
        - Hardware I/O interface
        - Plot visualization
        - User interface updates
        - Hardware event callbacks
    """
    def __init__(self):
        """
        Initialize GUI window, simulation backend, hardware interface,
        plots, timers, and hardware event handlers.
        """
        super().__init__()
        loadUi("Hardware_Integrated_GUI.ui", self)

        self.showMaximized()
        self.sim = CanduRealtimeSim(PlantParams())


        self.plot_window = 20
        self.display_refresh_rate = 33 #ms
        self.max_power = 982 # MW
        self.max_temperature = 1200

        # Setup all UI components
        self.setup_plots()
        self.setup_inputs()
        self.setup_outputs()

        # Setup Hardware
        self.HW = SimHardware()
        self.HW.GPIO_pin_init()
        self.setup_Hardware_Events()

        self.sim.run()
        self.setup_timers()
        self.reset_steady()




    def setup_plots(self):
        """
        Configure all real-time graph widgets and initialize plot traces.
        """
        # Neutron Power Graph
        self.neutronPowerGraph.setXRange(0, self.plot_window)
        self.neutronPowerGraph.setLabel('bottom', 'Time (seconds)')
        self.neutronPowerGraph.setLabel('left', 'Power (%FP)')
        self.neutronPowerGraph.setTitle('Neutron Power')
        self.neutronLine = self.neutronPowerGraph.plot()

        # Electric Power Graph
        self.electricPowerGraph.setLabel('bottom', 'Time (seconds)')
        self.electricPowerGraph.setLabel('left', 'Power (MW)')
        self.electricPowerGraph.setTitle('Electric Power (Scaled)')
        self.electricLine = self.electricPowerGraph.plot()

        # Temperature Graph Setup
        self.temperatureGraph.setXRange(0, self.plot_window)
        self.temperatureGraph.setLabel('bottom', 'Time (seconds)')
        self.temperatureGraph.setLabel('left', 'Temp (Degrees Celsius)')
        self.temperatureGraph.setTitle('Temperatures')
        self.lineTf = self.temperatureGraph.plot(name="Tf")

        # Pressure Graph Setup
        self.pressureGraph.setXRange(0, self.plot_window)
        self.pressureGraph.setLabel('bottom', 'Time (seconds)')
        self.pressureGraph.setLabel('left', 'Pressure (MPa)')
        self.pressureGraph.setTitle('Turbine/SC Pressure Proxy')
        self.pressureLine = self.pressureGraph.plot()

    def setup_inputs(self):
        """
        Connect GUI button inputs to simulation control callbacks.
        """
        # Reset Steady State Button
        self.steadyStateReset.clicked.connect(self.reset_steady)
        # Pause Button
        self.pauseButton.clicked.connect(self.pause_sim)
        self.resumeButton.clicked.connect(self.resume_sim)

    def setup_outputs(self):
        """
        Initialize LCD displays, labels, and console log outputs.
        """
        # Temperature & Power LCD
        self.temperatureLCD.display(self.sim.x.Tf)
        self.powerOutputLCD.display(self.sim.x.P)
        # Liquid Zone Control Value
        self.lzcValue.setText(f"{self.sim.ctrl.lzc_fill_pct}%")
        # Console log
        logText = "Window Initialized"
        self.consoleLog.setText(logText)
        self.consoleLog.ensureCursorVisible()

    def setup_timers(self):
        """
        Configure periodic timers for display refresh and elapsed time clock.
        """
        self.elapsed_minutes = 0
        self.displayTimer = QTimer()
        self.displayTimer.timeout.connect(self.update_display)
        self.displayTimer.start(self.display_refresh_rate)

        self.LCDTimer = QTimer()
        self.LCDTimer.timeout.connect(self.update_LCD)
        self.LCDTimer.start(60000)


    def update_plots(self):
        """
        Update all real-time simulation plots using current simulation history.

        Automatically rescales:
            - Time axis units
            - X-axis scrolling window
            - Y-axis ranges
        """
        if not self.sim._running:
            return

        if self.sim.ctrl.paused:
            return
        if self.sim.x.exploded:
            return

        t = np.asarray(self.sim.t_wall_hist)*self.sim.ctrl.time_scale
        P = np.asarray(self.sim.P_hist)
        Tf = np.asarray(self.sim.Tf_hist)
        Pe = np.asarray(self.sim.Pe_hist)
        pp = np.asarray(self.sim.p_hist)

        scaled_plot_window = self.plot_window*self.sim.ctrl.time_scale
        # Adjust X-Axis label based on time units
        if self.sim.ctrl.time_scale < 60:
            self.neutronPowerGraph.setLabel('bottom', 'time (seconds)')
            self.electricPowerGraph.setLabel('bottom', 'time (seconds)')
            self.pressureGraph.setLabel('bottom', 'time (seconds)')
            self.temperatureGraph.setLabel('bottom', 'time (seconds)')
        else:
            t = t/60 # Convert the plot axis to minutes
            scaled_plot_window = scaled_plot_window/60
            self.neutronPowerGraph.setLabel('bottom', 'time (minutes)')
            self.electricPowerGraph.setLabel('bottom', 'time (minutes)')
            self.pressureGraph.setLabel('bottom', 'time (minutes)')
            self.temperatureGraph.setLabel('bottom', 'time (minutes)')

        self.neutronLine.setData(t, 100.0 * P)
        self.lineTf.setData(t, Tf)
        self.electricLine.setData(t, Pe)
        self.pressureLine.setData(t, pp)

        # Handle x range of plot
        if t[-1] > scaled_plot_window:
            self.neutronPowerGraph.setXRange(t[-1] - scaled_plot_window, t[-1])
            self.electricPowerGraph.setXRange(t[-1] - scaled_plot_window, t[-1])
            self.pressureGraph.setXRange(t[-1] - scaled_plot_window, t[-1])
            self.temperatureGraph.setXRange(t[-1] - scaled_plot_window, t[-1])
        else:
            self.neutronPowerGraph.setXRange(0, scaled_plot_window)
            self.electricPowerGraph.setXRange(0, scaled_plot_window)
            self.pressureGraph.setXRange(0, scaled_plot_window)
            self.temperatureGraph.setXRange(0, scaled_plot_window)

        # Handle y range of plot
        self.neutronPowerGraph.setYRange(0, max(100.0 * P))
        self.electricPowerGraph.setYRange(0, max(Pe))
        self.pressureGraph.setYRange(0, max(pp))
        self.temperatureGraph.setYRange(0, max(Tf))


    def sample_inputs(self):
        """
        Sample all physical hardware inputs from ADC/GPIO and map them
        to simulation control parameters.

        Inputs include:
            - Liquid zone control
            - Adjuster rods
            - Simulation speed
            - Safety toggle
            - Mechanical control absorbers
            - Refuel rate
        """
        ADC_Values = self.HW.ADC.ADS1256_GetAll()

        # Liquid zone control
        Voltage = ADC_Values[pinouts.LZC_CH] * self.HW.ADC_REF_VOLTAGE / 0x7fffff
        Voltage = self.moving_average(Voltage, self.lzc_buffer)
        liquidZoneControl = Voltage/self.HW.MAX_ADC_VOLTAGE * 100
        self.sim.ctrl.lzc_fill_pct = liquidZoneControl
        # Adjuster rods
        Voltage = ADC_Values[pinouts.ADJ_RODS_CH] * self.HW.ADC_REF_VOLTAGE / 0x7fffff
        Voltage = self.moving_average(Voltage, self.adj_buffer)
        adjusterRods = (self.HW.MAX_ADC_VOLTAGE - Voltage)/ self.HW.MAX_ADC_VOLTAGE
        self.sim.ctrl.adj_out_frac = adjusterRods
        
        # Timescale/speed
        Voltage = self.HW.ADC.ADS1256_GetChannelValue(pinouts.SIM_SPEED_CH) * self.HW.ADC_REF_VOLTAGE / 0x7fffff
        
        noise_threshold = 0.2 # V
        if Voltage < noise_threshold:
            Voltage = Voltage
        elif Voltage > self.HW.MAX_ADC_VOLTAGE - noise_threshold:
            self.sim.ctrl.time_scale = 600
        elif Voltage > 5/6 * self.HW.MAX_ADC_VOLTAGE - noise_threshold:
            self.sim.ctrl.time_scale = 480
        elif Voltage > 4/6 * self.HW.MAX_ADC_VOLTAGE - noise_threshold:
            self.sim.ctrl.time_scale = 360
        elif Voltage > 3/6 * self.HW.MAX_ADC_VOLTAGE- noise_threshold:
            self.sim.ctrl.time_scale = 240
        elif Voltage > 2/6 * self.HW.MAX_ADC_VOLTAGE - noise_threshold:
            self.sim.ctrl.time_scale = 120
        else:
            self.sim.ctrl.time_scale = 60


        # Safety
        safety_enabled = GPIO.input(pinouts.SAFETY_TOGGLE_INPUT)
        self.sim.ctrl.safety_enabled = safety_enabled
        
        # mca Slider
        Voltage = ADC_Values[pinouts.MCA_CH] * self.HW.ADC_REF_VOLTAGE / 0x7fffff
        Voltage = self.moving_average(Voltage, self.mca_buffer)
        mechanicalControlAbsorbers = Voltage / self.HW.MAX_ADC_VOLTAGE
        self.sim.ctrl.mca_in_frac = mechanicalControlAbsorbers
        
        # refuel rate slider
        Voltage = ADC_Values[pinouts.REFUEL_CH] * self.HW.ADC_REF_VOLTAGE / 0x7fffff
        Voltage = self.moving_average(Voltage, self.refuel_buffer)
        refuelRate = (self.HW.MAX_ADC_VOLTAGE - Voltage)/ self.HW.MAX_ADC_VOLTAGE * 2
        self.sim.ctrl.refuel_rate_cmd = refuelRate


    def update_timescale_LCD(self):
        """
        Update simulation timescale display and unit conversion labels.
        """
        self.timescaleValue.setText(f"{self.sim.ctrl.time_scale}")
        if self.sim.ctrl.time_scale < 60:
            # Seconds case
            self.timescaleConversionLCD.display(self.sim.ctrl.time_scale)
            self.timescaleConversionLabel.setText("second in simulation")
        elif self.sim.ctrl.time_scale == 60:
            self.timescaleConversionLCD.display(self.sim.ctrl.time_scale / 60)
            self.timescaleConversionLabel.setText("minute in simulation")
        else:
            self.timescaleConversionLCD.display(self.sim.ctrl.time_scale / 60)
            self.timescaleConversionLabel.setText("minutes in simulation")
            

    def update_display(self):
        """
        Main GUI refresh loop.

        Performs:
            - Hardware input sampling
            - Plot updates
            - LCD refresh
            - DAC output updates
            - GPIO status light updates
            - Meltdown detection/handling
        """
        self.sample_inputs()
        # testing
        print("Siren enable pin:", GPIO.input(pinouts.SIREN_ENABLED))
        # update the data on the plots
        self.update_plots()

        # Handle reactor meltdown case
        if self.sim.x.exploded:
            # self.consoleLog.append("Reset Simulator to Steady State to Play Again")
            if GPIO.input(pinouts.SIREN_ENABLED):
                GPIO.output(pinouts.SIREN_OUTPUT, GPIO.HIGH)
            else:
                GPIO.output(pinouts.SIREN_OUTPUT, GPIO.LOW)
            self.reactorMeltdown()
        else:
            GPIO.output(pinouts.SIREN_OUTPUT, GPIO.LOW)

        self.temperatureLCD.display(f"{self.sim.x.Tf:.0f}")
        if self.sim.x.Tf > 800:
            self.temperatureLCD.setStyleSheet("QLCDNumber { color: red; }")
        elif self.sim.x.Tf > 720:
            self.temperatureLCD.setStyleSheet("QLCDNumber { color: orange; }")
        else:
            self.temperatureLCD.setStyleSheet("QLCDNumber { color: #00ff00; }")

        # Drive the temperature lights output
        Voltage = self.sim.x.Tf * self.HW.MAX_ADC_VOLTAGE/self.max_temperature
        self.HW.DAC.DAC8532_Out_Voltage(pinouts.TEMP_OUTPUT, Voltage)

        Power = self.sim.p.eta_electric * self.sim.x.P * self.sim.p.Q_th_full_MW
        self.powerOutputLCD.display(f"{Power:.0f}")

        # Update power output lights
        Voltage = Power * self.HW.MAX_ADC_VOLTAGE/self.max_power
        self.HW.DAC.DAC8532_Out_Voltage(pinouts.POWER_OUTPUT, Voltage)

        # Liquid zone control
        self.lzcValue.setText(f"{self.sim.ctrl.lzc_fill_pct:.0f}%")
        
        # Adjuster rods
        self.adjValue.setText(f"{self.sim.ctrl.adj_out_frac:.1f}")
        # Timescale/speed
        self.update_timescale_LCD()

        # mca Slider
        self.mcaValue.setText(f"{self.sim.ctrl.mca_in_frac:.1f}")
        # Refueling value
        self.refuelValue.setText(f"{self.sim.ctrl.refuel_rate_cmd:.1f}")

        # Update event status log
        for log in self.sim.ctrl.event_status:
            self.consoleLog.append(log)
            self.sim.ctrl.event_status.remove(log)

        # Update indicator lights
        if self.sim.ctrl.safety_enabled:
            GPIO.output(pinouts.SAFETY_ON_OUTPUT, GPIO.HIGH)
        else:
            GPIO.output(pinouts.SAFETY_ON_OUTPUT, GPIO.LOW)

        GPIO.output(pinouts.SIM_PAUSE_LIGHT_OUTPUT, self.sim.ctrl.paused)
        GPIO.output(pinouts.SIM_ON_LIGHT_OUTPUT, not self.sim.ctrl.paused)

        GPIO.output(pinouts.SDS1_STATUS, self.sim.x.sds1_active)
        GPIO.output(pinouts.SDS2_STATUS, self.sim.x.sds2_active)



    def update_LCD(self):
        """
        Increment and display elapsed simulation runtime in minutes.
        """
        self.elapsed_minutes += 1
        self.LCDClock.display(self.elapsed_minutes)

    def reset_steady(self, channel=None):
        """
        Reset simulation to steady-state conditions.

        Also:
            - Clears siren output
            - Pauses simulation after reset
            - Initializes ADC moving-average buffers

        Parameters:
            channel : int, optional
                GPIO callback channel number when triggered by hardware.
        """
        self.consoleLog.append("Resetting System to Steady State")

        # set simulation parameter
        self.sim.ctrl.request_reset_steady = True

        GPIO.output(pinouts.SIREN_OUTPUT, GPIO.LOW)
        # give sim time to reset to steadt
        time.sleep(50*0.001)
        self.sim.ctrl.paused = True
        self.sim._pause_start = time.time()
        GPIO.output(pinouts.SIM_PAUSE_LIGHT_OUTPUT, GPIO.HIGH)

        # Pre-fill buffers with current ADC readings so first sample is stable
        ADC_Values = self.HW.ADC.ADS1256_GetAll()
        init_lzc = ADC_Values[pinouts.LZC_CH] * self.HW.ADC_REF_VOLTAGE / 0x7fffff
        init_adj = ADC_Values[pinouts.ADJ_RODS_CH] * self.HW.ADC_REF_VOLTAGE / 0x7fffff
        init_mca = ADC_Values[pinouts.MCA_CH] * self.HW.ADC_REF_VOLTAGE / 0x7fffff
        init_refuel = ADC_Values[pinouts.REFUEL_CH] * self.HW.ADC_REF_VOLTAGE / 0x7fffff
        self.lzc_buffer = [init_lzc] * 5
        self.adj_buffer = [init_adj] * 5
        self.mca_buffer = [init_mca] * 5
        self.refuel_buffer = [init_refuel] * 5
        

    def pause_sim(self, channel=None):
        """
        Pause simulation and update hardware/GUI pause indicators.

        Parameters:
            channel : int, optional
                GPIO callback channel number when triggered by hardware.
        """
        self.sim.ctrl.paused = True
        GPIO.output(pinouts.SIM_PAUSE_LIGHT_OUTPUT, GPIO.HIGH)
        GPIO.output(pinouts.SIM_ON_LIGHT_OUTPUT, GPIO.LOW)
        self.sim._pause_start = time.time()
        self.pauseButton.setText("RESUME")
        self.consoleLog.append("~~~~ Pausing Simulation ~~~~")

    def resume_sim(self, channel=None):
        """
        Resume simulation and update hardware/GUI run indicators.

        Parameters:
            channel : int, optional
                GPIO callback channel number when triggered by hardware.
        """
        self.sim.ctrl.paused = False
        GPIO.output(pinouts.SIM_PAUSE_LIGHT_OUTPUT, GPIO.LOW)
        GPIO.output(pinouts.SIM_ON_LIGHT_OUTPUT, GPIO.HIGH)
        self.sim._paused_wall_time += time.time() - self.sim._pause_start
        self.sim._pause_start = None
        self.pauseButton.setText("PAUSE")
        self.consoleLog.append("~~~~ Resuming Simulation ~~~~")

    def reactorMeltdown(self):
        """
        Handle reactor meltdown event.

        Activates siren output if enabled and manages meltdown alert logic.
        """
        if GPIO.input(pinouts.SIREN_ENABLED):
            GPIO.output(pinouts.SIREN_OUTPUT, GPIO.HIGH)
        else:
            GPIO.output(pinouts.SIREN_OUTPUT, GPIO.LOW)


    def sds1_triggered(self, channel=None):
        """
        Trigger shutdown system 1 if not already active.

        Parameters:
            channel : int, optional
                GPIO callback channel.
        """
        # only trip if safety has not yet been enabled
        if not self.sim.ctrl.trip_sds1:
            self.sim.ctrl.trip_sds1 = True
            self.consoleLog.append("SDS1 Triggered")

    def sds2_triggered(self, channel=None):
        """
        Trigger shutdown system 2 if not already active.

        Parameters:
            channel : int, optional
                GPIO callback channel.
        """
        if not self.sim.ctrl.trip_sds2:
            self.sim.ctrl.trip_sds2 = True
            self.consoleLog.append("SDS2 Triggered")

    def setup_Hardware_Events(self):
        """
        Register GPIO interrupt callbacks for all hardware control inputs.
        """
        GPIO.add_event_detect(pinouts.RESET_SIM_INPUT, GPIO.FALLING, callback=self.reset_steady, bouncetime=100)
        GPIO.add_event_detect(pinouts.SIM_PAUSE_INPUT, GPIO.FALLING, callback=self.pause_sim, bouncetime=100)
        GPIO.add_event_detect(pinouts.SDS1_INPUT, GPIO.FALLING, callback=self.sds1_triggered, bouncetime=100)
        GPIO.add_event_detect(pinouts.SDS2_INPUT, GPIO.FALLING, callback=self.sds2_triggered, bouncetime=100)
        GPIO.add_event_detect(pinouts.SIM_ON_INPUT, GPIO.FALLING, callback=self.resume_sim, bouncetime=100)


    def closeEvent(self, event):
        """
        Safely terminate simulation thread when application closes.

        Parameters:
            event : QCloseEvent
                Qt close event object.
        """
        self.sim._running = False
        event.accept()

    def moving_average(self, new_val, buffer, N=5):
        """
        Apply moving-average filter to ADC input samples.

        Parameters:
            new_val : float
                New ADC voltage reading.
            buffer : list
                Rolling buffer of previous samples.
            N : int
                Moving average window size.

        Returns:
            float
                Filtered averaged value.
        """
        buffer.append(new_val)
        if len(buffer) > N:
            buffer.pop(0)
        return sum(buffer)/len(buffer)


class SimHardware():
    """
    Hardware abstraction layer for simulator ADC, DAC, and GPIO devices.

    Manages:
        - ADC initialization
        - DAC initialization
        - GPIO pin configuration
    """
    def __init__(self):
        """
        Initialize ADC/DAC hardware interfaces and hardware constants.
        """
        self.ADC_REF_VOLTAGE = 5.0 # Volts
        self.ADC = ADS1256.ADS1256()
        self.DAC = DAC8532.DAC8532()
        self.ADC.ADS1256_init()
        self.MAX_ADC_VOLTAGE = 3.0 # Volts

    def GPIO_pin_init(self):
        """
        Configure all Raspberry Pi GPIO pins for simulator hardware I/O.
        """
        GPIO.setup(pinouts.SDS1_INPUT, GPIO.IN, pull_up_down=GPIO.PUD_OFF)
        GPIO.setup(pinouts.SDS2_INPUT, GPIO.IN, pull_up_down=GPIO.PUD_OFF)
        GPIO.setup(pinouts.SAFETY_TOGGLE_INPUT, GPIO.IN, pull_up_down=GPIO.PUD_OFF)
        GPIO.setup(pinouts.SAFETY_ON_OUTPUT, GPIO.OUT)
        GPIO.setup(pinouts.SIREN_OUTPUT, GPIO.OUT)
        GPIO.setup(pinouts.SIM_ON_INPUT, GPIO.IN, pull_up_down=GPIO.PUD_OFF)
        GPIO.setup(pinouts.SIM_ON_LIGHT_OUTPUT, GPIO.OUT)
        GPIO.setup(pinouts.USER_ACTION_LIGHT_OUTPUT, GPIO.OUT)
        GPIO.setup(pinouts.SIM_PAUSE_INPUT, GPIO.IN, pull_up_down=GPIO.PUD_OFF)
        GPIO.setup(pinouts.SIM_PAUSE_LIGHT_OUTPUT, GPIO.OUT)
        GPIO.setup(pinouts.RESET_SIM_INPUT, GPIO.IN, pull_up_down=GPIO.PUD_OFF)
        GPIO.setup(pinouts.SIREN_ENABLED, GPIO.IN, pull_up_down=GPIO.PUD_OFF)
        GPIO.setup(pinouts.SDS1_STATUS, GPIO.OUT)
        GPIO.setup(pinouts.SDS2_STATUS, GPIO.OUT)





# ============================================================
# Application Entry Point
# ============================================================
if __name__ == "__main__":
    app = QApplication([])

    globals()["PlotWidget"] = pg.PlotWidget

    window = MainGUIWindow()
    window.show()

    app.exec()

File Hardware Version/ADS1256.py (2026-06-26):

import config
import RPi.GPIO as GPIO


ScanMode = 0


# gain channel
ADS1256_GAIN_E = {'ADS1256_GAIN_1' : 0, # GAIN   1
                  'ADS1256_GAIN_2' : 1,	# GAIN   2
                  'ADS1256_GAIN_4' : 2,	# GAIN   4
                  'ADS1256_GAIN_8' : 3,	# GAIN   8
                  'ADS1256_GAIN_16' : 4,# GAIN  16
                  'ADS1256_GAIN_32' : 5,# GAIN  32
                  'ADS1256_GAIN_64' : 6,# GAIN  64
                 }

# data rate
ADS1256_DRATE_E = {'ADS1256_30000SPS' : 0xF0, # reset the default values
                   'ADS1256_15000SPS' : 0xE0,
                   'ADS1256_7500SPS' : 0xD0,
                   'ADS1256_3750SPS' : 0xC0,
                   'ADS1256_2000SPS' : 0xB0,
                   'ADS1256_1000SPS' : 0xA1,
                   'ADS1256_500SPS' : 0x92,
                   'ADS1256_100SPS' : 0x82,
                   'ADS1256_60SPS' : 0x72,
                   'ADS1256_50SPS' : 0x63,
                   'ADS1256_30SPS' : 0x53,
                   'ADS1256_25SPS' : 0x43,
                   'ADS1256_15SPS' : 0x33,
                   'ADS1256_10SPS' : 0x20,
                   'ADS1256_5SPS' : 0x13,
                   'ADS1256_2d5SPS' : 0x03
                  }

# registration definition
REG_E = {'REG_STATUS' : 0,  # x1H
         'REG_MUX' : 1,     # 01H
         'REG_ADCON' : 2,   # 20H
         'REG_DRATE' : 3,   # F0H
         'REG_IO' : 4,      # E0H
         'REG_OFC0' : 5,    # xxH
         'REG_OFC1' : 6,    # xxH
         'REG_OFC2' : 7,    # xxH
         'REG_FSC0' : 8,    # xxH
         'REG_FSC1' : 9,    # xxH
         'REG_FSC2' : 10,   # xxH
        }

# command definition
CMD = {'CMD_WAKEUP' : 0x00,     # Completes SYNC and Exits Standby Mode 0000  0000 (00h)
       'CMD_RDATA' : 0x01,      # Read Data 0000  0001 (01h)
       'CMD_RDATAC' : 0x03,     # Read Data Continuously 0000   0011 (03h)
       'CMD_SDATAC' : 0x0F,     # Stop Read Data Continuously 0000   1111 (0Fh)
       'CMD_RREG' : 0x10,       # Read from REG rrr 0001 rrrr (1xh)
       'CMD_WREG' : 0x50,       # Write to REG rrr 0101 rrrr (5xh)
       'CMD_SELFCAL' : 0xF0,    # Offset and Gain Self-Calibration 1111    0000 (F0h)
       'CMD_SELFOCAL' : 0xF1,   # Offset Self-Calibration 1111    0001 (F1h)
       'CMD_SELFGCAL' : 0xF2,   # Gain Self-Calibration 1111    0010 (F2h)
       'CMD_SYSOCAL' : 0xF3,    # System Offset Calibration 1111   0011 (F3h)
       'CMD_SYSGCAL' : 0xF4,    # System Gain Calibration 1111    0100 (F4h)
       'CMD_SYNC' : 0xFC,       # Synchronize the A/D Conversion 1111   1100 (FCh)
       'CMD_STANDBY' : 0xFD,    # Begin Standby Mode 1111   1101 (FDh)
       'CMD_RESET' : 0xFE,      # Reset to Power-Up Values 1111   1110 (FEh)
      }

class ADS1256:
    def __init__(self):
        self.rst_pin = config.RST_PIN
        self.cs_pin = config.CS_PIN
        self.drdy_pin = config.DRDY_PIN

    # Hardware reset
    def ADS1256_reset(self):
        config.digital_write(self.rst_pin, GPIO.HIGH)
        config.delay_ms(200)
        config.digital_write(self.rst_pin, GPIO.LOW)
        config.delay_ms(200)
        config.digital_write(self.rst_pin, GPIO.HIGH)
    
    def ADS1256_WriteCmd(self, reg):
        config.digital_write(self.cs_pin, GPIO.LOW)#cs  0
        config.spi_writebyte([reg])
        config.digital_write(self.cs_pin, GPIO.HIGH)#cs 1
    
    def ADS1256_WriteReg(self, reg, data):
        config.digital_write(self.cs_pin, GPIO.LOW)#cs  0
        config.spi_writebyte([CMD['CMD_WREG'] | reg, 0x00, data])
        config.digital_write(self.cs_pin, GPIO.HIGH)#cs 1
        
    def ADS1256_Read_data(self, reg):
        config.digital_write(self.cs_pin, GPIO.LOW)#cs  0
        config.spi_writebyte([CMD['CMD_RREG'] | reg, 0x00])
        data = config.spi_readbytes(1)
        config.digital_write(self.cs_pin, GPIO.HIGH)#cs 1

        return data
        
    def ADS1256_WaitDRDY(self):
        for i in range(0,400000,1):
            if(config.digital_read(self.drdy_pin) == 0):
                
                break
        if(i >= 400000):
            print ("Time Out ...\r\n")
        
        
    def ADS1256_ReadChipID(self):
        self.ADS1256_WaitDRDY()
        id = self.ADS1256_Read_data(REG_E['REG_STATUS'])
        id = id[0] >> 4
        # print 'ID',id
        return id
        
    #The configuration parameters of ADC, gain and data rate
    def ADS1256_ConfigADC(self, gain, drate):
        self.ADS1256_WaitDRDY()
        buf = [0,0,0,0,0,0,0,0]
        buf[0] = (0<<3) | (1<<2) | (1<<1)  # Set bit 1 high to enable Buffer
        #buf[0] = (0<<3) | (1<<2) | (0<<1)  # Set bit 1 low to disable Buffer
        buf[1] = 0x08
        buf[2] = (0<<5) | (0<<3) | (gain<<0)
        buf[3] = drate
        
        config.digital_write(self.cs_pin, GPIO.LOW)#cs  0
        config.spi_writebyte([CMD['CMD_WREG'] | 0, 0x03])
        config.spi_writebyte(buf)
        
        config.digital_write(self.cs_pin, GPIO.HIGH)#cs 1
        config.delay_ms(1) 



    def ADS1256_SetChannel(self, channel):
        if channel > 7:
            return 0
        self.ADS1256_WriteReg(REG_E['REG_MUX'], (channel<<4) | (1<<3))

    def ADS1256_SetDiffChannel(self, channel):
        if channel == 0:
            self.ADS1256_WriteReg(REG_E['REG_MUX'], (0 << 4) | 1) 	#Diffchannel  AIN0-AIN1
        elif channel == 1:
            self.ADS1256_WriteReg(REG_E['REG_MUX'], (2 << 4) | 3) 	#Diffchannel   AIN2-AIN3
        elif channel == 2:
            self.ADS1256_WriteReg(REG_E['REG_MUX'], (4 << 4) | 5) 	#Diffchannel    AIN4-AIN5
        elif channel == 3:
            self.ADS1256_WriteReg(REG_E['REG_MUX'], (6 << 4) | 7) 	#Diffchannel   AIN6-AIN7

    def ADS1256_SetMode(self, Mode):
        ScanMode = Mode

    def ADS1256_init(self):
        if (config.module_init() != 0):
            return -1
        self.ADS1256_reset()
        id = self.ADS1256_ReadChipID()
        if id == 3 :
            print("ID Read success  ")
        else:
            print("ID Read failed   ")
            return -1
        self.ADS1256_ConfigADC(ADS1256_GAIN_E['ADS1256_GAIN_1'], ADS1256_DRATE_E['ADS1256_15000SPS'])
        #self.ADS1256_ConfigADC(ADS1256_GAIN_E['ADS1256_GAIN_1'], ADS1256_DRATE_E['ADS1256_5SPS'])
        
        # Check if buffer was enabled
        status_reg = bin(self.ADS1256_Read_data(REG_E['REG_STATUS'])[0])
        print("Status Register: "+str(status_reg))
        return 0
        
    def ADS1256_Read_ADC_Data(self):
        self.ADS1256_WaitDRDY()
        config.digital_write(self.cs_pin, GPIO.LOW)#cs  0
        config.spi_writebyte([CMD['CMD_RDATA']])
        # config.delay_ms(10)
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
